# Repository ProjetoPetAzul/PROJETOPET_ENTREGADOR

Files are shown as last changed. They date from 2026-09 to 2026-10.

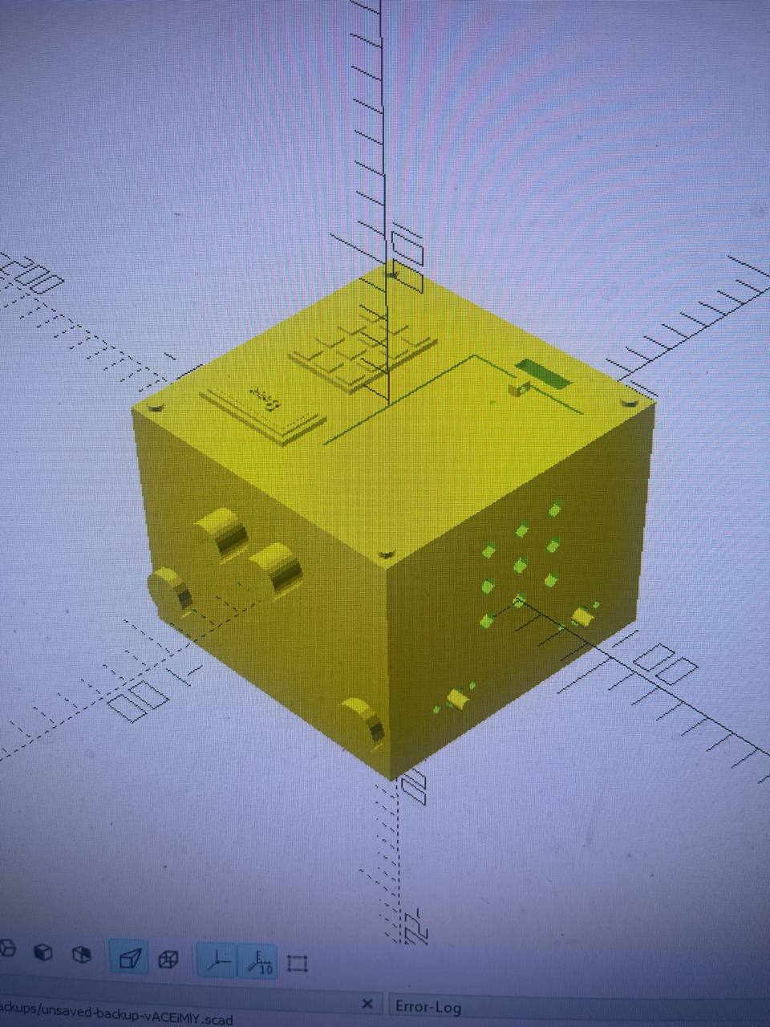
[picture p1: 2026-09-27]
media/images/openscad/photo_5010759403480747098_y.jpg

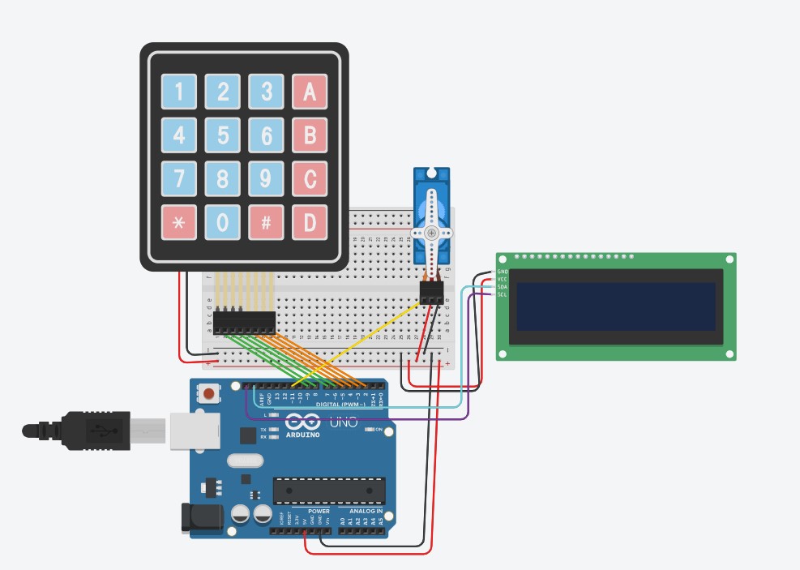
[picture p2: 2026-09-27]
media/images/tinkercad/Captura de tela 2026-09-27 202220.jpg

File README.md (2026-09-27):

# Robô Entregador

Projeto desenvolvido para a etapa **Core Project** do processo seletivo 2026.2 do **PET Engenharia de Computação — UFC**.

## Sobre o projeto

O **Robô Entregador** é uma proposta de robô autônomo desenvolvido para realizar o transporte de objetos entre diferentes pontos do **Centro de Tecnologia (CT) da Universidade Federal do Ceará (UFC)**.

A ideia consiste em selecionar um destino, realizar a coleta de um objeto e conduzi-lo autonomamente até o ponto escolhido, utilizando mecanismos de navegação, detecção de obstáculos e controle do compartimento de carga.

Durante o período de desenvolvimento do Core Project, a construção de um robô físico completamente funcional para navegação pelo CT não era viável. Por isso, a equipe desenvolveu um **protótipo integrado**, representando as principais partes necessárias para a construção do robô real:

* 🔌 **Eletrônica e controle**, desenvolvidos e simulados no Tinkercad com Arduino e C++;
* ⚙️ **Chassi e estrutura mecânica**, modelados em OpenSCAD;
* 🌐 **Simulação da navegação e do comportamento do robô**, desenvolvida no Webots.

O repositório reúne os códigos, modelos, documentação, simulações e materiais utilizados durante o desenvolvimento do projeto.

---

## Navegação pelo projeto

O repositório está organizado de acordo com as principais frentes de desenvolvimento do Robô Entregador.

| Seção | Conteúdo |
| --- | --- |
| 📚 [`docs/`](docs/) | Documentação técnica do projeto, incluindo eletrônica, mecânica, software, Webots e testes. |
| 📖 [`manual/`](manual/) | Manual do projeto, com orientações para utilização e compreensão do protótipo. |
| 🔌 [`arduino/`](arduino/) | Códigos dos Arduinos utilizados no sistema. |
| ⚙️ [`openscad/`](openscad/) | Modelo e arquivos relacionados ao chassi desenvolvido em OpenSCAD. |
| 🌐 [`webots/`](webots/) | Arquivos da simulação desenvolvida no Webots, incluindo mundo, textura e controlador. |
| 🖼️ [`media/`](media/) | Imagens, vídeos e materiais visuais do desenvolvimento e da apresentação. |
| 🔗 [`links/recursos.md`](links/recursos.md) | Links para recursos externos utilizados no projeto, incluindo o circuito desenvolvido no Tinkercad. |

---

## Visão geral do desenvolvimento

O projeto foi desenvolvido de forma modular, dividindo o protótipo em três frentes principais.

### Eletrônica e controle

Responsável pelo controle dos motores, sensores, teclado, display, iluminação, detecção de obstáculos e gerenciamento do compartimento de carga.

A implementação foi desenvolvida e testada no **Tinkercad**, utilizando dois Arduinos e comunicação entre eles por I²C.

➡️ [Ver documentação da eletrônica](docs/eletronica.md)

### Estrutura mecânica

O chassi e os elementos estruturais do robô foram modelados em **OpenSCAD**, considerando o posicionamento dos componentes eletrônicos e o compartimento destinado ao transporte da carga.

➡️ [Ver documentação mecânica](docs/mecanica.md)

### Simulação

O comportamento de navegação do robô foi representado no **Webots**, utilizando uma simulação baseada no ambiente do Centro de Tecnologia.

➡️ [Ver documentação do Webots](docs/webots.md)

---

## Desenvolvimento e testes

O projeto foi desenvolvido de forma incremental, com testes realizados ao longo das diferentes etapas de implementação.

A eletrônica passou por versões progressivas no Tinkercad, desde uma primeira abordagem simplificada até a integração de seleção de destino, teclado, senha, display e controle do compartimento de carga.

Também foram realizados testes das rotas e do comportamento de navegação na simulação do Webots. A integração física completa do robô não foi realizada durante o período do projeto, devido às limitações de tempo e recursos disponíveis.

➡️ [Ver histórico de desenvolvimento e testes](docs/testes.md)

---

## Recursos

### Circuito no Tinkercad

O circuito eletrônico desenvolvido durante o projeto pode ser acessado diretamente no Tinkercad:

➡️ [Abrir projeto no Tinkercad](links/recursos.md)

### Apresentação

Os slides utilizados na apresentação do projeto serão disponibilizados nesta seção futuramente.

➡️ [`media/slides/`](media/slides/)

---

## Estrutura do repositório

```text
robo-entregador/
├── README.md
├── arduino/
│   ├── mestre/
│   └── escravo/
├── docs/
├── manual/
├── media/
│   ├── images/
│   │   ├── tinkercad/
│   │   ├── openscad/
│   │   ├── webots/
│   │   └── prototipo/
│   ├── slides/
│   └── videos/
├── openscad/
├── webots/
└── links/
    └── recursos.md
```

Cada diretório possui uma função específica dentro do projeto, permitindo separar os códigos, modelos, documentação, simulações e materiais complementares.

---

## Equipe

Projeto desenvolvido por:

* **[HECTOR PIMENTA AVILA CAVALCANTE]**
* **[LIVIA SARAIVA DA COSTA]**
* **[MARCIO ROSA BEZERRA CAVALCANTE]**
* **[RENAN ARAUJO GONZALEZ]**

### Instituição

**Universidade Federal do Ceará — UFC**
**PET Engenharia de Computação**

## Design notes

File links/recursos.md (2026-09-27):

# Recursos externos

## Tinkercad

[🔗 Acessar o circuito do Robô Entregador no Tinkercad](https://www.tinkercad.com/things/074Hag8RQTY-robo-entregador-v4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)

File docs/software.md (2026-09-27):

# Software, Controle e Navegação

## 1. Visão geral

O software do **ROBÔ ENTREGADOR** é responsável por integrar as informações dos sensores, controlar os atuadores e coordenar todo o fluxo de operação do robô.

O firmware principal foi desenvolvido para Arduino utilizando **C++**, enquanto um segundo Arduino é utilizado especificamente para a leitura do teclado matricial.

A lógica do robô é organizada através de uma **máquina de estados**, permitindo separar as diferentes etapas da operação:

```text
Seleção do destino
        ↓
Preparação da carga
        ↓
Geração da senha
        ↓
Preparação da navegação
        ↓
Deslocamento
        ↓
Chegada ao destino
        ↓
Autenticação
        ↓
Entrega da carga
        ↓
Nova viagem
```

---

# 2. Organização do software

O firmware principal está localizado em:

```text
arduino/
└── mestre/
    └── mestre.ino
```

O firmware responsável pelo teclado está localizado em:

```text
arduino/
└── escravo/
    └── escravo.ino
```

O `mestre.ino` concentra a lógica principal do robô.

O `escravo.ino` realiza a leitura do teclado e disponibiliza as teclas através da comunicação I²C.

---

# 3. Máquina de estados

O comportamento do robô é controlado por estados que representam cada etapa da operação.

Os estados implementados são:

```text
ESCOLHENDO_DESTINO
AGUARDANDO_CARGA
MOSTRANDO_SENHA
DEVOLVENDO_CARGA
MANOBRA_INICIAL
SAINDO_DA_ORIGEM
EM_VIAGEM
AGUARDANDO_SENHA
PORTA_ABERTA
SISTEMA_BLOQUEADO
```

A utilização dessa estrutura evita que todas as operações sejam executadas simultaneamente e permite que cada etapa tenha suas próprias condições de entrada, execução e saída.

---

# 4. Estado `ESCOLHENDO_DESTINO`

É o estado inicial de operação do robô.

O sistema permanece parado e aguarda que o usuário informe a estação de destino através do teclado.

As estações disponíveis são:

```text
A
B
C
D
```

O destino não pode ser igual à estação atualmente ocupada pelo robô.

Após a seleção, o usuário utiliza:

```text
# → confirmar
* → cancelar
```

Quando o destino é confirmado, o sistema passa para:

```text
AGUARDANDO_CARGA
```

---

# 5. Estado `AGUARDANDO_CARGA`

Nesse estado, o compartimento de carga é aberto.

O sistema aguarda que o usuário coloque a carga no compartimento.

O usuário pode:

```text
# → confirmar que a carga foi colocada
* → cancelar
```

Caso a operação seja confirmada, o sistema fecha o compartimento e prepara a viagem.

Caso o usuário cancele, o compartimento é fechado e o sistema retorna à seleção de destino.

---

# 6. Geração da senha da viagem

Após a confirmação da carga, o firmware gera uma senha de quatro dígitos para a viagem.

A geração utiliza:

```cpp
random(0, 10)
```

O gerador é inicializado através de:

```cpp
randomSeed(micros());
```

A senha é apresentada no LCD antes do início do deslocamento.

O usuário precisa confirmar o início da viagem através da tecla:

```text
#
```

---

# 7. Estado `MOSTRANDO_SENHA`

Nesse estado, a senha da viagem permanece disponível para o usuário.

A senha funciona como uma credencial para retirar a carga na estação de destino.

O usuário pode iniciar a viagem pressionando:

```text
#
```

Também é possível cancelar a viagem através de:

```text
*
```

Nesse caso, o sistema passa para:

```text
DEVOLVENDO_CARGA
```

---

# 8. Estado `DEVOLVENDO_CARGA`

Esse estado trata o cancelamento de uma viagem depois que a carga já foi colocada no compartimento.

O fluxo é:

```text
Viagem cancelada
       ↓
Abrir compartimento
       ↓
Usuário retira a carga
       ↓
Fechar compartimento
       ↓
Retornar à seleção de destino
```

Dessa forma, uma viagem pode ser cancelada antes do deslocamento sem deixar a carga presa dentro do compartimento.

---

# 9. Representação da posição

O sistema representa a posição do robô através da estação atual.

As estações disponíveis são:

```text
A
B
C
D
```

Além da estação, o firmware mantém a orientação física do robô.

As orientações possíveis são:

```text
NORTE
LESTE
SUL
OESTE
```

Portanto, a navegação utiliza duas informações:

```text
Estação atual
+
Orientação atual
```

Exemplo:

```text
Estação atual = B
Orientação = OESTE
```

---

# 10. Rotas

As rotas entre as estações são determinadas pela função:

```cpp
obterDirecaoDestino()
```

O firmware possui as seguintes relações:

| Origem | Destino | Direção |
| --- | --- | --- |
| A | B | Leste |
| A | C | Norte |
| A | D | Oeste |
| B | A | Sul |
| B | C | Norte |
| B | D | Leste |
| C | A | Sul |
| C | B | Leste |
| C | D | Oeste |
| D | A | Leste |
| D | B | Oeste |
| D | C | Norte |

Essa tabela permite transformar a escolha do usuário em uma direção física necessária para o deslocamento.

---

# 11. Cálculo da manobra

Depois de determinar a direção desejada, o firmware compara essa direção com a orientação atual do robô.

A função utilizada é:

```cpp
calcularManobra()
```

As possibilidades são:

```text
RETO
DIREITA
ESQUERDA
U
```

Exemplo:

```text
Orientação atual: NORTE
Direção desejada: LESTE
```

Resultado:

```text
DIREITA
```

Outro exemplo:

```text
Orientação atual: NORTE
Direção desejada: OESTE
```

Resultado:

```text
ESQUERDA
```

Quando a direção desejada é oposta à orientação atual, é utilizada uma manobra de retorno em U.

---

# 12. Estado `MANOBRA_INICIAL`

Antes de iniciar o deslocamento, o robô precisa alinhar sua orientação com a direção da viagem.

Esse procedimento ocorre no estado:

```text
MANOBRA_INICIAL
```

Os tempos configurados no firmware são:

```text
Curva: 700 ms
Manobra U: 1400 ms
```

Se a orientação atual já estiver alinhada com a direção desejada, o robô segue sem realizar uma curva adicional.

---

# 13. Estado `SAINDO_DA_ORIGEM`

Após realizar a manobra inicial, o robô precisa deixar a região correspondente à estação de origem.

Isso é necessário porque a estação de origem continua sendo detectável enquanto o robô ainda estiver sobre sua marca.

O estado:

```text
SAINDO_DA_ORIGEM
```

mantém o robô seguindo a linha até que a estação de origem deixe de ser detectada.

O fluxo é:

```text
MANOBRA_INICIAL
       ↓
Seguir linha
       ↓
Ainda detecta origem?
    ↙          ↘
  SIM          NÃO
   ↓             ↓
Continua      EM_VIAGEM
```

---

# 14. Seguidor de linha

Durante o deslocamento, o robô utiliza três LDRs para determinar a posição da linha.

As leituras correspondem a:

```text
LDR esquerdo
LDR central
LDR direito
```

O firmware utiliza o limiar:

```text
300
```

Uma leitura inferior a esse valor é interpretada como detecção da linha.

---

# 15. Estratégia de recuperação da linha

O software mantém a variável:

```cpp
ultimaDirecao
```

Ela registra a última tendência conhecida do movimento:

```text
-1 → esquerda
 0 → frente
+1 → direita
```

Quando nenhum dos três sensores detecta a linha momentaneamente, o firmware utiliza essa informação para tentar recuperar a trajetória.

Isso permite que uma perda momentânea da linha não resulte imediatamente em uma interrupção completa do deslocamento.

---

# 16. Controle do movimento

O firmware possui comandos para controlar o movimento dos motores.

Os principais comportamentos são:

```text
Frente
Direita
Esquerda
Parada
```

Os movimentos de curva são realizados através do acionamento diferenciado dos motores.

Para uma curva à direita:

```text
Motor esquerdo → frente
Motor direito  → trás
```

Para uma curva à esquerda:

```text
Motor esquerdo → trás
Motor direito  → frente
```

Para uma parada:

```text
PWM esquerdo → 0
PWM direito  → 0
```

---

# 17. Estado `EM_VIAGEM`

Esse é o principal estado de deslocamento do robô.

Durante a viagem, o software realiza continuamente:

```text
Verificação de obstáculos
        ↓
Seguimento da linha
        ↓
Detecção de estação
```

A detecção de obstáculos possui prioridade sobre o seguimento da linha.

Quando uma estação é detectada depois que o robô deixou a origem, ela é considerada a estação de destino.

---

# 18. Detecção do destino

Durante a viagem, o sistema verifica continuamente os sensores responsáveis pela identificação das estações.

Quando uma estação é detectada:

```text
Motores → parada
```

O firmware atualiza:

```text
estacaoAtual
direcaoAtual
```

A orientação obtida é calculada através de:

```cpp
obterOrientacaoChegada()
```

Em seguida, o sistema passa para a etapa de autenticação.

---

# 19. Atualização da orientação

A orientação física do robô é atualizada após cada viagem.

Isso permite que a próxima viagem considere a posição final deixada pela viagem anterior.

Assim, o planejamento de uma nova rota utiliza:

```text
estação atual
+
orientação atual
+
estação de destino
```

Essa abordagem permite calcular a próxima manobra sem precisar assumir que o robô sempre começa voltado para a mesma direção.

---

# 20. Detecção de obstáculos

A navegação possui dois sensores ultrassônicos.

O software verifica a distância medida pelos sensores e considera que existe um obstáculo quando qualquer um deles apresenta distância inferior a:

```text
30 cm
```

Quando um obstáculo é detectado:

```text
Parar motores
```

O robô permanece parado enquanto a condição de obstáculo persistir.

---

# 21. Atualização das leituras ultrassônicas

As leituras dos sensores ultrassônicos são atualizadas aproximadamente a cada:

```text
100 ms
```

A leitura utiliza:

```cpp
pulseIn(echo, HIGH, 30000)
```

O timeout utilizado é de aproximadamente:

```text
30 ms
```

Quando não há retorno do sinal dentro desse período, o firmware considera que não existe obstáculo detectado dentro da condição utilizada.

---

# 22. Prioridade dos obstáculos

Durante a viagem, a lógica pode ser representada por:

```text
              EM_VIAGEM
                  ↓
        Verificar obstáculo
                  ↓
          Existe obstáculo?
             ↙         ↘
           SIM         NÃO
            ↓            ↓
      Parar motores   Seguir linha
            ↓            ↓
       Aguardar       Verificar
                      estação
```

Caso o obstáculo permaneça por aproximadamente dois segundos, o LCD apresenta:

```text
OBSTACULO NA VIA
```

Quando a condição deixa de existir, o sistema retoma o fluxo normal da viagem.

---

# 23. Estado `AGUARDANDO_SENHA`

Após identificar a estação de destino, o robô permanece parado e solicita a senha da viagem.

O usuário deve informar os quatro dígitos através do teclado.

Por questões de segurança visual, os valores digitados são apresentados no LCD como:

```text
*
```

A tecla:

```text
*
```

pode ser utilizada para limpar a entrada atual.

A tecla:

```text
#
```

confirma a senha.

---

# 24. Validação da senha

O firmware compara a senha digitada com a senha gerada no início da viagem.

Caso os valores sejam iguais:

```text
Senha correta
       ↓
Acesso liberado
       ↓
Abrir compartimento
       ↓
Retirar carga
```

O sistema então passa para:

```text
PORTA_ABERTA
```

---

# 25. Tentativas de autenticação

O sistema permite até:

```text
3 tentativas
```

de autenticação para cada viagem.

Quando a senha está incorreta, o número de tentativas restantes é atualizado.

Depois de três tentativas incorretas, o sistema entra em:

```text
SISTEMA_BLOQUEADO
```

O código de manutenção utilizado para desbloqueio é definido diretamente no firmware e não é apresentado nesta documentação.

---

# 26. Estado `SISTEMA_BLOQUEADO`

Nesse estado, o sistema deixa de aceitar a senha normal da viagem.

O usuário precisa realizar o procedimento de manutenção definido pelo firmware.

Após a autenticação de manutenção, o sistema pode retornar ao fluxo de autenticação.

Essa estrutura impede que a mesma senha da viagem continue sendo testada indefinidamente.

---

# 27. Estado `PORTA_ABERTA`

Quando a senha correta é informada, o compartimento é aberto.

O LCD informa que a carga pode ser retirada.

Após a retirada, o usuário pode utilizar:

```text
#
```

ou:

```text
*
```

para finalizar a operação.

O servo então fecha o compartimento e o sistema retorna para:

```text
ESCOLHENDO_DESTINO
```

---

# 28. Comunicação com o teclado

O Arduino principal não realiza diretamente a varredura da matriz do teclado.

Essa função é executada pelo segundo Arduino.

A comunicação entre os dois dispositivos ocorre através de I²C.

O Arduino do teclado possui o endereço:

```text
0x10
```

O Arduino principal realiza uma requisição e o Arduino 2 retorna o caractere armazenado.

---

# 29. Estados sem leitura do teclado

Durante o deslocamento, não é necessário consultar o teclado.

Por isso, as requisições de teclado não são realizadas durante:

```text
MANOBRA_INICIAL
SAINDO_DA_ORIGEM
EM_VIAGEM
```

O teclado é consultado principalmente nos estados em que existe uma interação direta com o usuário.

Essa organização evita que a leitura do teclado interfira desnecessariamente na execução da navegação.

---

# 30. Controle do compartimento

O compartimento é controlado através de um micro servo.

As posições utilizadas são:

```text
0°  → fechado
90° → aberto
```

O software realiza a abertura e o fechamento conforme o estado atual do sistema.

A abertura ocorre principalmente durante:

```text
AGUARDANDO_CARGA
PORTA_ABERTA
```

Também pode ocorrer durante o processo de cancelamento para permitir a retirada da carga.

---

# 31. Fluxo completo de operação

O funcionamento completo pode ser representado por:

```text
INÍCIO
  ↓
ESCOLHENDO_DESTINO
  ↓
Selecionar destino
  ↓
Confirmar
  ↓
AGUARDANDO_CARGA
  ↓
Colocar carga
  ↓
Confirmar
  ↓
MOSTRANDO_SENHA
  ↓
Gerar senha
  ↓
Confirmar início
  ↓
MANOBRA_INICIAL
  ↓
SAINDO_DA_ORIGEM
  ↓
EM_VIAGEM
  ↓
Seguir linha
  ↓
Verificar obstáculos
  ↓
Detectar destino
  ↓
AGUARDANDO_SENHA
  ↓
Informar senha
  ↓
Senha correta?
 ↙          ↘
SIM         NÃO
 ↓           ↓
PORTA_       Tentativa
ABERTA       novamente
 ↓
Retirar carga
 ↓
Fechar compartimento
 ↓
ESCOLHENDO_DESTINO
```

---

# 32. Fluxo de cancelamento

O cancelamento antes do deslocamento segue:

```text
AGUARDANDO_CARGA
        ↓
Carga colocada
        ↓
MOSTRANDO_SENHA
        ↓
Usuário pressiona *
        ↓
DEVOLVENDO_CARGA
        ↓
Abrir compartimento
        ↓
Retirar carga
        ↓
Fechar compartimento
        ↓
ESCOLHENDO_DESTINO
```

---

# 33. Fluxo de bloqueio

Quando a autenticação falha três vezes:

```text
AGUARDANDO_SENHA
        ↓
Tentativa 1
        ↓
Tentativa 2
        ↓
Tentativa 3
        ↓
SISTEMA_BLOQUEADO
        ↓
Procedimento de manutenção
        ↓
Retorno à autenticação
```

---

# 34. Inicialização do software

Durante o `setup()`, o firmware realiza as configurações iniciais do sistema.

Entre elas:

1. configuração dos pinos;
2. inicialização da comunicação I²C;
3. configuração do LCD;
4. configuração dos sensores;
5. configuração do controle dos motores;
6. desligamento dos LEDs;
7. parada dos motores;
8. fechamento do compartimento;
9. inicialização do gerador aleatório;
10. definição da estação inicial;
11. definição da orientação inicial;
12. apresentação da tela inicial.

A condição inicial é:

```text
Estação = A
Orientação = NORTE
```

---

# 35. Parâmetros de controle

Os principais parâmetros utilizados pelo software são:

| Parâmetro | Valor |
| --- | ---: |
| Velocidade dos motores | 128 |
| Limiar dos LDRs de linha | 300 |
| Limiar dos sensores de estação | 100 |
| Distância para obstáculo | 30 cm |
| Atualização ultrassônica |  100 ms |
| Timeout ultrassônico | 30 ms |
| Tempo de curva |  700 ms |
| Tempo da manobra U | 1400 ms |
| Tempo do servo |  500 ms |
| Tentativas de senha | 3 |

Esses valores estão definidos diretamente no firmware e podem ser ajustados durante o desenvolvimento e os testes do protótipo.

---

# 36. Estrutura lógica do firmware

A organização geral do programa pode ser representada como:

```text
Configuração
     ↓
Definição de estados
     ↓
Definição de direções
     ↓
Definição de manobras
     ↓
Controle de motores
     ↓
Leitura dos sensores
     ↓
Seguidor de linha
     ↓
Detecção de estações
     ↓
Detecção de obstáculos
     ↓
Controle do servo
     ↓
Comunicação I²C
     ↓
Interface com usuário
     ↓
Senhas
     ↓
Máquina de estados
```

Essa estrutura permite que cada subsistema tenha uma responsabilidade definida dentro do funcionamento do robô.

---

# 37. Integração entre software e hardware

O software funciona como a camada responsável por interpretar os sensores e controlar os atuadores.

A relação pode ser representada por:

```text
                 SENSORES
                    ↓
          ┌──────────────────┐
          │ Arduino Principal│
          │                  │
          │ Máquina de       │
          │ estados          │
          │                  │
          │ Navegação        │
          └────────┬─────────┘
                   ↓
        ┌──────────┼──────────┐
        ↓          ↓          ↓
     MOTORES     SERVO      LEDs
        ↓          ↓          ↓
    Movimento  Compart.   Indicação

                   ↕
                  I²C
                   ↕
          ┌────────────────┐
          │   Arduino 2    │
          └───────┬────────┘
                  ↓
             TECLADO 4×4
```

O Arduino principal funciona como o núcleo de decisão do sistema, enquanto o segundo Arduino atua como uma interface dedicada para entrada de dados.

---

# 38. Arquivos relacionados

Os principais arquivos relacionados ao software são:

```text
arduino/
├── mestre/
│   └── mestre.ino
└── escravo/
    └── escravo.ino
```

O arquivo `mestre.ino` contém:

* máquina de estados;
* navegação;
* controle dos motores;
* leitura dos sensores;
* controle do servo;
* controle do LCD;
* comunicação I²C;
* gerenciamento das senhas.

O arquivo `escravo.ino` contém:

* varredura do teclado;
* identificação das teclas;
* armazenamento temporário da tecla;
* resposta às requisições I²C.

---

# 39. Relação com as outras etapas do projeto

O software integra as demais partes desenvolvidas no projeto:

```text
Eletrônica
    ↓
Sensores e atuadores
    ↓
Software
    ↓
Controle e navegação
    ↓
Mecânica
    ↓
Estrutura física
    ↓
Webots
    ↓
Simulação do comportamento
```

Dessa forma, o firmware representa a camada de controle que conecta os componentes eletrônicos à lógica de operação do robô.

---

## 40. Arquivos do projeto

| Área | Arquivo |
| --- | --- |
| Firmware principal  | `arduino/mestre/mestre.ino` |
| Firmware do teclado | `arduino/escravo/escravo.ino` |
| Modelo mecânico | `openscad/chassi.scad` |
| Simulação | `webots/` |

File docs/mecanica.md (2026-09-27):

# Mecânica e Modelagem 3D

## 1. Visão geral

A estrutura mecânica do **ROBÔ ENTREGADOR** foi desenvolvida utilizando **OpenSCAD**, permitindo criar um modelo paramétrico do chassi e dos principais elementos externos do protótipo.

O projeto foi pensado para representar a estrutura física de um robô móvel capaz de transportar uma carga, integrando:

* chassi;
* tampa superior;
* compartimento de carga;
* alçapão;
* pontos de fixação;
* suportes internos;
* aberturas para sensores;
* representação dos componentes eletrônicos externos.

A modelagem foi construída de forma paramétrica, permitindo alterar dimensões e características da estrutura diretamente através das variáveis do código.

---

## 2. Arquivo do modelo

O modelo mecânico está localizado em:

```text
openscad/
└── chassi.scad
```

O arquivo contém a definição das principais peças e também uma montagem final do conjunto.

---

## 3. Dimensões principais

As dimensões principais utilizadas no modelo são:

| Parâmetro |  Valor |
| --- | -----: |
| Largura do chassi |  48 mm |
| Comprimento do chassi | 104 mm |
| Altura do chassi |  65 mm |
| Espessura das paredes | 3 mm |
| Distância da quina | 4 mm |
| Raio dos furos de parafuso | 1,6 mm |

Esses valores são definidos no início do arquivo OpenSCAD, permitindo que o modelo seja facilmente ajustado.

---

## 4. Estrutura do chassi

O corpo principal do chassi é construído a partir de um volume retangular com:

```text
48 mm × 104 mm × 65 mm
```

A estrutura externa é posteriormente modificada para criar o espaço interno do robô.

A espessura das paredes é definida por:

```text
3 mm
```

Isso permite representar uma carcaça com volume interno suficiente para acomodar os componentes do sistema.

---

## 5. Base modular

A parte inferior do chassi possui uma matriz de furos inspirada no padrão de montagem utilizado em peças LEGO.

A configuração principal utiliza uma matriz de:

```text
6 × 13
```

Essa característica permite representar pontos de fixação distribuídos pela base.

Além da matriz principal, existem furos adicionais nas extensões laterais da estrutura.

---

## 6. Extensões laterais

O modelo possui uma extensão lateral localizada na região inferior do chassi.

Essa extensão possui aproximadamente:

```text
64 mm de largura
24 mm de comprimento
5 mm de altura
```

Também são adicionados furos de montagem nessa região.

Essas extensões fazem parte da geometria da base e ampliam as possibilidades de fixação da estrutura.

---

## 7. Compartimento de carga

Um dos principais elementos mecânicos do projeto é o compartimento destinado ao transporte da carga.

A estrutura possui uma região elevada na tampa para representar o compartimento.

As dimensões principais utilizadas nessa região são aproximadamente:

```text
26 mm × 35 mm × 15 mm
```

O compartimento é integrado ao modelo da tampa e possui pontos próprios de fixação.

---

## 8. Alçapão

O acesso ao compartimento de carga é representado através de um **alçapão**.

A peça possui espessura aproximada de:

```text
1,2 mm
```

O modelo também inclui elementos geométricos para representar:

* a porta do compartimento;
* a região de abertura;
* uma alça;
* o mecanismo semelhante a uma dobradiça.

No protótipo eletrônico, a abertura do compartimento é realizada por um micro servo. O modelo mecânico representa a estrutura física correspondente a esse mecanismo.

---

## 9. Fixação da tampa

A tampa superior possui quatro pontos de fixação localizados nas regiões de canto.

Esses pontos são representados através de furos para parafusos.

O modelo também possui quatro torres internas de montagem, destinadas à representação dos pontos de suporte internos da estrutura.

---

## 10. Aberturas para sensores ultrassônicos

A parte frontal do chassi possui duas aberturas destinadas aos sensores ultrassônicos.

Os furos são modelados com raio aproximado de:

```text
8,2 mm
```

A disposição dos dois furos representa a posição dos sensores utilizados para detectar obstáculos à frente do robô.

---

## 11. Abertura para chave

Na região traseira do chassi existe um recorte destinado à representação de uma **chave gangorra**.

O modelo da chave também foi criado no próprio OpenSCAD para permitir sua visualização durante a montagem.

---

## 12. Ventilação

O chassi possui aberturas laterais destinadas à representação de entradas e saídas de ventilação.

Essas aberturas fazem parte da geometria lateral da carcaça.

---

## 13. Componentes representados no modelo

Além da estrutura principal, o arquivo OpenSCAD possui modelos simplificados de alguns componentes utilizados no protótipo.

Entre eles estão:

* sensores ultrassônicos;
* chave gangorra;
* LCD;
* teclado matricial;
* parafusos.

Esses modelos não têm como objetivo reproduzir todos os detalhes construtivos dos componentes comerciais, mas representar suas dimensões e posições dentro da montagem.

---

## 14. Modelo do sensor ultrassônico

O sensor ultrassônico é representado por um modelo aproximado de:

```text
45 mm × 2 mm × 20 mm
```

A parte frontal possui dois elementos cilíndricos com aproximadamente:

```text
8 mm de raio
```

A representação permite visualizar a posição dos sensores em relação à abertura frontal do chassi.

---

## 15. Modelo do LCD

O display LCD é representado por um modelo simplificado com dimensões aproximadas de:

```text
40 mm × 20 mm × 2 mm
```

Também é incluída uma representação textual na superfície do display para facilitar sua identificação na montagem.

---

## 16. Modelo do teclado

O teclado matricial é representado por uma placa com dimensões aproximadas de:

```text
30 mm × 40 mm × 2 mm
```

A superfície possui uma representação das teclas em uma matriz de:

```text
3 × 4
```

O objetivo dessa modelagem é representar a posição e o volume ocupado pelo dispositivo na estrutura do protótipo.

---

## 17. Modelo da chave gangorra

A chave gangorra possui um modelo simplificado próprio dentro do arquivo OpenSCAD.

Sua função na montagem é representar visualmente o componente instalado na parte traseira do chassi.

---

## 18. Modelo dos parafusos

Os parafusos utilizados nos pontos de fixação são representados através de uma geometria simplificada.

A dimensão relacionada ao raio do parafuso é definida pelo parâmetro:

```text
raio_parafuso = 1,6 mm
```

Essa parametrização permite ajustar os furos de fixação de acordo com a necessidade do modelo.

---

## 19. Organização do código OpenSCAD

O arquivo foi organizado em módulos, permitindo construir cada parte da estrutura separadamente.

Entre as principais funções geométricas estão:

```text
chassi()
tampa()
alcapao()
parafuso()
sensor_ultrassonico()
chave_gangorra()
tela_lcd()
teclado()
```

Essa organização facilita a edição individual dos componentes e a montagem final do protótipo.

---

## 20. Montagem final

Após a definição das peças individuais, o arquivo realiza a montagem do conjunto.

A montagem integra:

```text
Chassi
   ↓
Tampa
   ↓
Alçapão
   ↓
Parafusos
   ↓
Sensores ultrassônicos
   ↓
Chave gangorra
   ↓
LCD
   ↓
Teclado
```

Dessa forma, é possível visualizar a relação espacial entre a estrutura mecânica e os principais componentes externos do robô.

---

## 21. Relação entre mecânica e eletrônica

A modelagem mecânica foi desenvolvida considerando os componentes utilizados na implementação eletrônica.

A estrutura possui regiões específicas para:

* sensores ultrassônicos;
* LCD;
* teclado;
* chave;
* compartimento de carga;
* pontos de fixação;
* componentes internos.

Assim, o modelo não representa somente uma carcaça, mas uma proposta de integração entre a estrutura física e os subsistemas eletrônicos do robô.

---

## 22. Relação com o projeto do robô

O modelo mecânico representa uma etapa do desenvolvimento do protótipo do **ROBÔ ENTREGADOR**.

A proposta geral do projeto é integrar:

```text
Mecânica
   +
Eletrônica
   +
Software
   +
Simulação
```

A modelagem em OpenSCAD permite representar como esses sistemas poderiam ser fisicamente integrados em uma versão construída do robô.

---

## 23. Arquivo relacionado

O modelo completo está disponível no repositório em:

```text
openscad/chassi.scad
```

O arquivo pode ser aberto e editado no **OpenSCAD**, permitindo visualizar a geometria, modificar os parâmetros e gerar novamente o modelo tridimensional.

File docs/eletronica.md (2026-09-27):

# Eletrônica e Firmware

## 1. Visão geral

O **ROBÔ ENTREGADOR** é um protótipo de robô móvel autônomo desenvolvido para transportar uma carga entre quatro estações identificadas pelas letras **A, B, C e D**.

A implementação eletrônica combina:

* Arduino;
* dois motores DC;
* driver L293D;
* três sensores LDR para seguimento de linha;
* sensores para identificação das estações;
* dois sensores ultrassônicos;
* micro servo para acionamento do compartimento de carga;
* display LCD 16×2 com comunicação I²C;
* expansor de I/O PCF8574;
* teclado matricial 4×4;
* comunicação I²C entre dois Arduinos.

O sistema de controle é organizado por uma **máquina de estados**, permitindo separar as etapas de interação com o usuário, preparação da carga, navegação e entrega.

---

## 2. Arquitetura eletrônica

O sistema utiliza dois Arduinos.

### Arduino principal

O Arduino principal concentra a lógica de controle e é responsável por:

* controle dos motores;
* leitura dos sensores de linha;
* detecção das estações;
* leitura dos sensores ultrassônicos;
* controle do servo;
* controle do LCD;
* controle dos LEDs através do PCF8574;
* comunicação com o Arduino do teclado;
* geração das senhas;
* validação das senhas;
* controle das tentativas;
* lógica de navegação;
* máquina de estados.

### Arduino 2

O segundo Arduino é dedicado ao teclado matricial 4×4.

Ele:

1. realiza a varredura das linhas e colunas;
2. identifica a tecla pressionada;
3. armazena temporariamente o caractere;
4. disponibiliza a tecla através do barramento I²C.

O Arduino 2 funciona como **escravo I²C no endereço `0x10`**.

Essa divisão permite separar a leitura do teclado da lógica principal do robô.

---

# 3. Componentes principais

| Componente | Função |
| --- | --- |
| Arduino principal | Controle central do robô |
| Arduino 2 | Leitura do teclado |
| L293D | Acionamento dos motores DC |
| 2 motores DC | Deslocamento do robô |
| 3 LDRs | Seguimento da linha |
| Sensores de estação | Identificação das estações |
| 2 HC-SR04 | Detecção de obstáculos |
| Micro servo | Abertura e fechamento do compartimento |
| LCD 16×2 I²C | Interface de usuário |
| PCF8574 | Expansão de saídas para LEDs |
| Teclado 4×4 | Entrada de comandos e senhas |

---

# 4. Pinagem do Arduino principal

## 4.1 Motores

| Pino | Função |
| ---- | --- |
| D5 | PWM do motor esquerdo |
| D6 | PWM do motor direito  |
| D7 | IN1 do motor esquerdo |
| D8 | IN2 do motor esquerdo |
| D9 | IN1 do motor direito  |
| D10  | IN2 do motor direito  |

O controle dos motores é realizado através do **L293D**.

A velocidade padrão configurada no firmware é:

```text
128 / 255
```

---

## 4.2 Sensores do seguidor de linha

| Pino | Sensor |
| ---- | --- |
| A0 | LDR esquerdo |
| A1 | LDR central  |
| A2 | LDR direito  |

O firmware utiliza:

```text
LIMIAR_LDR = 300
```

A condição utilizada é:

```text
valor < 300 → linha detectada
```

---

## 4.3 Sensores de estação

| Pino | Função |
| ---- | --- |
| A3 | LDR esquerdo da estação |
| D4 | Sensor digital direito da estação |

Uma estação somente é considerada detectada quando as duas condições são satisfeitas:

```text
LDR esquerdo < 100
E
sensor digital = LOW
```

A utilização simultânea dos dois sensores reduz a possibilidade de uma leitura isolada ser interpretada como uma estação.

---

## 4.4 Sensores ultrassônicos

### Sensor esquerdo

| Função | Pino |
| --- | ---- |
| TRIG | D11  |
| ECHO | D12  |

### Sensor direito

| Função | Pino |
| --- | ---- |
| TRIG | D3 |
| ECHO | D13  |

O limite configurado para detecção de obstáculos é:

```text
30 cm
```

---

## 4.5 Servo

| Pino | Função |
| ---- | --- |
| D2 | Servo do compartimento |

Posições utilizadas pelo firmware:

```text
0°  → fechado
90° → aberto
```

O tempo configurado para movimentação é de:

```text
500 ms
```

---

# 5. Seguidor de linha

O robô utiliza três LDRs para acompanhar a pista.

As leituras são convertidas em estados booleanos de acordo com o limiar configurado.

### Principais combinações

| Esquerdo | Centro | Direito | Ação |
| --- | --- | --- | --- |
| 1 | 0 | 0 | Virar à esquerda |
| 1 | 1 | 0 | Virar à esquerda |
| 0 | 1 | 0 | Seguir em frente |
| 0 | 1 | 1 | Virar à direita |
| 0 | 0 | 1 | Virar à direita |
| 0 | 0 | 0 | Utilizar última direção |
| Outros | | | Seguir em frente |

O firmware mantém a variável:

```cpp
ultimaDirecao
```

Ela registra a última tendência de movimento:

```text
-1 → esquerda
 0 → frente
+1 → direita
```

Quando nenhum sensor detecta a linha momentaneamente, o robô utiliza essa informação para tentar recuperar a trajetória.

---

# 6. Controle dos motores

O firmware possui quatro movimentos básicos.

### Frente

Os dois motores giram para frente.

### Direita

O motor esquerdo gira para frente e o direito para trás.

### Esquerda

O motor esquerdo gira para trás e o direito para frente.

### Parada

Os dois sinais PWM são zerados.

Essa configuração também permite realizar giros aproximadamente sobre o próprio eixo.

---

# 7. Detecção de obstáculos

A detecção de obstáculos é realizada por dois sensores ultrassônicos.

O firmware mede a distância dos dois sensores e considera que existe obstáculo quando qualquer um deles retorna uma distância inferior a:

```text
30 cm
```

Quando um obstáculo é identificado:

```text
motores → parada
```

O robô permanece parado enquanto a condição de obstáculo persistir.

---

## 7.1 Timeout dos sensores

A leitura dos HC-SR04 utiliza:

```cpp
pulseIn(echo, HIGH, 30000)
```

Portanto, o tempo máximo de espera pelo eco é de aproximadamente:

```text
30 ms
```

Quando não há retorno dentro desse período, o firmware considera que não existe obstáculo dentro do alcance utilizado.

---

## 7.2 Cache das leituras

As leituras dos sensores ultrassônicos são atualizadas em intervalos de aproximadamente:

```text
100 ms
```

Isso evita executar continuamente os dois `pulseIn()` em todas as iterações do `loop()`.

Dessa forma, o sistema mantém uma resposta adequada aos obstáculos sem bloquear excessivamente o restante da lógica.

---

# 8. Detecção das estações

As estações são identificadas através da combinação de dois sensores.

O firmware utiliza:

```cpp
LDR_EST_ESQ = A3
LDR_EST_DIR = 4
```

A estação é considerada detectada somente quando:

```text
LDR da estação < 100
```

e:

```text
sensor digital = LOW
```

Essa condição é importante durante a navegação porque o robô utiliza a detecção da estação para determinar quando chegou ao destino.

---

# 9. Sistema de navegação

O sistema possui quatro estações:

```text
A
B
C
D
```

Além da estação atual, o firmware mantém a orientação física do robô.

As orientações possíveis são:

```text
NORTE
LESTE
SUL
OESTE
```

Assim, o estado de navegação não é representado somente por:

```text
estação atual = B
```

mas também por:

```text
estação atual = B
orientação atual = OESTE
```

Essa informação permite calcular a manobra necessária para a próxima viagem.

---

# 10. Direção do destino

A função:

```cpp
obterDirecaoDestino()
```

determina a direção física necessária para cada combinação de origem e destino.

As rotas implementadas são:

| Origem | Destino | Direção |
| --- | --- | --- |
| A | B | Leste |
| A | C | Norte |
| A | D | Oeste |
| B | A | Sul |
| B | C | Norte |
| B | D | Leste |
| C | A | Sul |
| C | B | Leste |
| C | D | Oeste |
| D | A | Leste |
| D | B | Oeste |
| D | C | Norte |

---

# 11. Orientação após a chegada

A função:

```cpp
obterOrientacaoChegada()
```

atualiza a orientação física do robô após cada deslocamento.

Isso permite que uma viagem seguinte utilize a orientação obtida na viagem anterior.

A posição e a orientação são, portanto, informações independentes.

---

# 12. Cálculo da manobra

A função:

```cpp
calcularManobra()
```

compara:

```text
direcaoAtual
```

com:

```text
direcaoDesejada
```

e seleciona uma das seguintes manobras:

```text
RETO
DIREITA
ESQUERDA
U
```

### Exemplo

Se:

```text
direção atual = NORTE
direção desejada = LESTE
```

a manobra é:

```text
DIREITA
```

Se:

```text
direção atual = NORTE
direção desejada = OESTE
```

a manobra é:

```text
ESQUERDA
```

Quando as direções são opostas, o firmware utiliza:

```text
U
```

---

# 13. Manobra inicial

Antes de iniciar o seguimento da linha, o robô executa a manobra necessária para alinhar sua orientação com a direção do deslocamento.

Os tempos configurados são:

```text
Curva: 700 ms
Retorno U: 1400 ms
```

Essa etapa é controlada pelo estado:

```text
MANOBRA_INICIAL
```

Se o robô estiver na direção correta, nenhuma curva adicional é realizada.

---

# 14. Saída da estação de origem

O estado:

```text
SAINDO_DA_ORIGEM
```

evita que a própria estação de origem seja imediatamente interpretada como destino.

O fluxo é:

```text
Manobra inicial
      ↓
Começa a seguir a linha
      ↓
Ainda está sobre a origem?
      ↓
Sim → continua
      ↓
Não
      ↓
EM_VIAGEM
```

Somente depois que a condição da estação de origem deixa de ser detectada o sistema passa a procurar a estação de destino.

---

# 15. Viagem

Durante o estado:

```text
EM_VIAGEM
```

o firmware executa continuamente:

1. verificação de obstáculos;
2. parada caso exista obstáculo;
3. seguimento da linha;
4. detecção de estação.

Quando uma estação é detectada depois que o robô deixou a origem:

```text
motores → parada
```

O firmware então atualiza:

```text
estacaoAtual
direcaoAtual
```

e inicia o processo de autenticação no destino.

---

# 16. Comunicação I²C

O Arduino principal utiliza o barramento I²C através dos pinos:

```text
A4 → SDA
A5 → SCL
```

Os dispositivos conectados ao barramento são:

| Dispositivo | Endereço |
| --- | --- |
| LCD 16×2 | `0x27` |
| PCF8574 | `0x20` |
| Arduino 2 | `0x10` |

A velocidade configurada no firmware é:

```text
400 kHz
```

---

# 17. LCD

O display utilizado é um:

```text
LCD 16×2 I²C
```

com endereço:

```text
0x27
```

Ele apresenta as informações necessárias para a operação do robô.

Exemplos de telas:

```text
ORIGEM: A
DESTINO? (A-D)
```

```text
DESTINO: B
#=OK *=VOLTA
```

```text
COLOQUE A CARGA
#=OK *=CANCELA
```

```text
A -> B
EM VIAGEM
```

```text
DIGITE A SENHA
____
```

---

# 18. PCF8574 e LEDs

O PCF8574 é utilizado como expansor de entradas e saídas.

Endereço:

```text
0x20
```

Os LEDs utilizam lógica ativa em nível baixo:

```text
LOW  → ligado
HIGH → desligado
```

Mapeamento utilizado:

| Pino | Função |
| ---- | --- |
| P4 | LED da estação B |
| P5 | LED da estação C |
| P6 | LED da estação D |
| P7 | LED associado à estação A |

Durante uma viagem, o LED correspondente ao destino é ativado.

Após a chegada, os LEDs são desligados.

---

# 19. Arduino 2 — teclado

O Arduino 2 funciona como escravo I²C:

```text
endereço = 0x10
```

O teclado utilizado é uma matriz 4×4.

### Linhas

| Linha | Pino |
| ----- | ---- |
| R1 | D2 |
| R2 | D3 |
| R3 | D4 |
| R4 | D5 |

### Colunas

| Coluna | Pino |
| --- | ---- |
| C1 | D6 |
| C2 | D7 |
| C3 | D8 |
| C4 | D9 |

O mapeamento das teclas é:

```text
1  2  3  A
4  5  6  B
7  8  9  C
*  0  #  D
```

O Arduino 2 realiza a varredura da matriz e armazena a tecla pressionada.

Quando recebe uma requisição I²C do Arduino principal, envia o caractere armazenado.

---

# 20. Controle do teclado

O Arduino principal consulta o teclado somente nos estados em que uma entrada do usuário é necessária.

Durante:

```text
MANOBRA_INICIAL
SAINDO_DA_ORIGEM
EM_VIAGEM
```

não são realizadas requisições de teclado.

O intervalo mínimo entre leituras é:

```text
50 ms
```

No Arduino 2 também existe uma pequena espera para evitar múltiplas leituras da mesma tecla.

---

# 21. Compartimento de carga

O compartimento é acionado por um micro servo.

Posições:

```text
0°  → fechado
90° → aberto
```

O servo é acionado somente quando necessário.

### Abertura

Pode ocorrer:

* antes da colocação da carga;
* quando a viagem é cancelada após a carga ter sido colocada;
* quando a senha do destino é validada.

### Fechamento

Pode ocorrer:

* após a colocação da carga;
* durante o cancelamento;
* após a retirada da carga;
* durante a inicialização do sistema.

---

# 22. Sistema de senha

Cada viagem possui uma senha de quatro dígitos.

A senha é gerada através do gerador pseudoaleatório do Arduino:

```cpp
random(0, 10)
```

O gerador é inicializado utilizando:

```cpp
randomSeed(micros());
```

A senha é apresentada ao usuário antes do início da viagem.

O usuário precisa pressionar `#` para iniciar o deslocamento.

---

# 23. Cancelamento antes da viagem

Depois que a carga é colocada e a senha é apresentada, o usuário pode cancelar a viagem através da tecla:

```text
*
```

Nesse caso:

1. o compartimento é reaberto;
2. o usuário retira a carga;
3. o compartimento é fechado;
4. o sistema retorna à seleção de destino.

Essa etapa é representada pelo estado:

```text
DEVOLVENDO_CARGA
```

---

# 24. Autenticação no destino

Quando o robô chega ao destino, solicita a senha da viagem.

Os dígitos digitados são apresentados como:

```text
*
```

em vez dos valores reais.

A tecla:

```text
*
```

limpa a senha atual.

A tecla:

```text
#
```

confirma a entrada.

---

# 25. Senha correta

Quando a senha está correta:

```text
ACESSO LIBERADO
RETIRE A CARGA
```

O servo abre o compartimento.

O usuário retira a carga.

Depois, `#` ou `*` fecha o compartimento e o sistema retorna à seleção de uma nova viagem.

---

# 26. Tentativas de autenticação

O firmware permite até:

```text
3 tentativas
```

de senha para a viagem.

Após três tentativas incorretas, o sistema entra no estado:

```text
SISTEMA_BLOQUEADO
```

Nesse estado, a senha normal da viagem deixa de ser processada e o sistema solicita o código de manutenção definido no firmware.

O código de manutenção é armazenado diretamente no programa e deve ser tratado como uma informação de configuração do protótipo.

---

# 27. Máquina de estados

O funcionamento do sistema é organizado através dos seguintes estados:

```text
ESCOLHENDO_DESTINO
AGUARDANDO_CARGA
MOSTRANDO_SENHA
DEVOLVENDO_CARGA
MANOBRA_INICIAL
SAINDO_DA_ORIGEM
EM_VIAGEM
AGUARDANDO_SENHA
PORTA_ABERTA
SISTEMA_BLOQUEADO
```

Fluxo principal:

```text
ESCOLHENDO_DESTINO
        ↓
AGUARDANDO_CARGA
        ↓
MOSTRANDO_SENHA
        ↓
MANOBRA_INICIAL
        ↓
SAINDO_DA_ORIGEM
        ↓
EM_VIAGEM
        ↓
AGUARDANDO_SENHA
        ↓
PORTA_ABERTA
        ↓
ESCOLHENDO_DESTINO
```

Fluxo de cancelamento:

```text
MOSTRANDO_SENHA
        ↓
DEVOLVENDO_CARGA
        ↓
ESCOLHENDO_DESTINO
```

Fluxo de bloqueio:

```text
AGUARDANDO_SENHA
        ↓
3 tentativas incorretas
        ↓
SISTEMA_BLOQUEADO
        ↓
código de manutenção
        ↓
AGUARDANDO_SENHA
```

---

# 28. Estados do sistema

### `ESCOLHENDO_DESTINO`

O robô está parado aguardando a seleção da estação de destino.

### `AGUARDANDO_CARGA`

O compartimento está aberto aguardando a colocação da carga.

### `MOSTRANDO_SENHA`

A senha da viagem foi gerada e está sendo apresentada ao usuário.

### `DEVOLVENDO_CARGA`

A viagem foi cancelada depois que a carga foi colocada.

### `MANOBRA_INICIAL`

O robô executa a curva necessária antes de iniciar o deslocamento.

### `SAINDO_DA_ORIGEM`

O robô deixa a marca da estação inicial.

### `EM_VIAGEM`

O robô realiza o seguimento da linha e monitora obstáculos e estações.

### `AGUARDANDO_SENHA`

O robô chegou ao destino e aguarda a autenticação.

### `PORTA_ABERTA`

A senha foi validada e o usuário pode retirar a carga.

### `SISTEMA_BLOQUEADO`

O limite de tentativas foi atingido e o sistema aguarda o procedimento de manutenção.

---

# 29. Proteção contra obstáculos durante a navegação

A verificação de obstáculos possui prioridade sobre o seguimento de linha.

A lógica durante o deslocamento é:

```text
Verificar obstáculo
       ↓
Existe obstáculo?
   ↙          ↘
 SIM          NÃO
 ↓             ↓
Parar       Seguir linha
 ↓             ↓
Aguardar     Verificar estação
```

Se o obstáculo permanecer por aproximadamente:

```text
2 segundos
```

o LCD apresenta:

```text
OBSTACULO NA VIA
```

Esse aviso possui função visual e não altera a lógica de navegação.

Quando o caminho é liberado, o sistema retorna à indicação normal da viagem.

---

# 30. Inicialização

Durante o `setup()`, o firmware:

1. configura os pinos dos motores;
2. configura os sensores ultrassônicos;
3. configura o sensor digital de estação;
4. inicia o barramento I²C;
5. configura o I²C em 400 kHz;
6. inicializa o LCD;
7. desliga os LEDs;
8. para os motores;
9. fecha o compartimento;
10. define a estação inicial como A;
11. define a orientação inicial como Norte;
12. inicializa o gerador aleatório;
13. apresenta a tela inicial.

A condição inicial é:

```text
Estação = A
Orientação = Norte
```

---

# 31. Pinagem completa

| Pino | Função |
| ---- | --- |
| D0 | Livre |
| D1 | Livre |
| D2 | Servo |
| D3 | TRIG ultrassônico direito  |
| D4 | Sensor digital de estação  |
| D5 | PWM motor esquerdo |
| D6 | PWM motor direito |
| D7 | Direção motor esquerdo |
| D8 | Direção motor esquerdo |
| D9 | Direção motor direito |
| D10  | Direção motor direito |
| D11  | TRIG ultrassônico esquerdo |
| D12  | ECHO ultrassônico esquerdo |
| D13  | ECHO ultrassônico direito  |
| A0 | LDR linha esquerdo |
| A1 | LDR linha central |
| A2 | LDR linha direito |
| A3 | LDR estação esquerdo |
| A4 | SDA |
| A5 | SCL |

---

# 32. Parâmetros principais

| Parâmetro | Valor |
| --- | ---: |
| Velocidade dos motores | 128 |
| Limiar LDR de linha | 300 |
| Limiar LDR de estação | 100 |
| Distância de obstáculo | 30 cm |
| Timeout ultrassônico | 30 ms |
| Intervalo das leituras ultrassônicas |  100 ms |
| Intervalo de leitura do teclado | 50 ms |
| Tempo de curva |  700 ms |
| Tempo da manobra U | 1400 ms |
| Tempo de movimentação do servo |  500 ms |
| Máximo de tentativas da senha | 3 |
| Endereço LCD |  `0x27` |
| Endereço PCF8574 |  `0x20` |
| Endereço Arduino 2 |  `0x10` |
| Frequência I²C | 400 kHz |

---

# 33. Organização do firmware

O firmware principal está dividido logicamente em módulos:

```text
Configuração de pinos
        ↓
Configurações
        ↓
Direções e manobras
        ↓
Máquina de estados
        ↓
Interface LCD
        ↓
Controle dos motores
        ↓
Seguidor de linha
        ↓
Detecção de estação
        ↓
Sensores ultrassônicos
        ↓
Servo
        ↓
LEDs / PCF8574
        ↓
Navegação
        ↓
Teclado / I²C
        ↓
Senhas
        ↓
Máquina de estados
        ↓
setup()
        ↓
loop()
```

Essa organização facilita a manutenção do código e separa as responsabilidades de cada subsistema.

---

# 34. Relação entre eletrônica e software

O funcionamento do robô depende da integração entre sensores, atuadores e software.

```text
             ┌──────────────┐
             │   SENSORES   │
             └──────┬───────┘
                    ↓
             ┌──────────────┐
             │   ARDUINO    │
             │   PRINCIPAL  │
             └──────┬───────┘
                    ↓
       ┌────────────┼────────────┐
       ↓            ↓            ↓
    MOTORES       SERVO       PCF8574
       ↓            ↓            ↓
   Movimento    Compart.      LEDs
       
                    ↕
                 I²C
                    ↕
             ┌──────────────┐
             │  ARDUINO 2   │
             └──────┬───────┘
                    ↓
               TECLADO 4×4
```

O Arduino principal integra as informações dos sensores com a máquina de estados e determina as ações do robô.

---

# 35. Arquivos relacionados

O firmware do projeto está separado em dois arquivos:

```text
arduino/
├── mestre/
│   └── mestre.ino
└── escravo/
    └── escravo.ino
```

O arquivo `mestre.ino` contém a lógica principal do robô.

O arquivo `escravo.ino` contém a implementação do Arduino responsável pelo teclado.

A simulação eletrônica complementar foi desenvolvida no **Tinkercad Circuits**.

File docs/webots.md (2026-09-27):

# Simulação no Webots

## 1. Visão geral

A simulação do **ROBÔ ENTREGADOR** foi desenvolvida utilizando o **Webots**, com o objetivo de representar virtualmente o comportamento do robô e o ambiente no qual ele deverá operar.

A utilização da simulação complementa as outras duas frentes do protótipo:

```text
Eletrônica
     +
Modelagem mecânica
     +
Simulação
```

Enquanto a eletrônica representa o sistema de controle e seus componentes, e o OpenSCAD representa a estrutura mecânica, o Webots permite representar o comportamento do robô em um ambiente virtual.

---

## 2. Objetivo da simulação

A simulação foi desenvolvida para representar o conceito de um robô móvel realizando deslocamentos entre diferentes pontos.

No contexto do projeto, o ambiente utilizado representa o **Centro de Tecnologia (CT) da Universidade Federal do Ceará (UFC)**.

A simulação permite visualizar uma representação virtual do ambiente e desenvolver o comportamento de navegação antes da construção de uma versão física completa.

---

## 3. Organização dos arquivos

Os arquivos relacionados ao Webots estão organizados no repositório da seguinte forma:

```text
webots/
├── controllers/
│   └── rota_3_pontos/
│       └── rota_3_pontos.py
│
└── worlds/
    ├── textures/
    │   └── centro_de_tecnologia.jpg
    ├── .criar.jpg
    ├── .criar.wbproj
    └── criar.wbt
```

Essa organização mantém os arquivos da simulação separados das demais partes do projeto.

---

## 4. Mundo da simulação

O mundo principal utilizado na simulação está localizado em:

```text
webots/worlds/criar.wbt
```

O arquivo `.wbt` contém a definição do ambiente utilizado pelo Webots.

A estrutura do mundo está associada à representação do ambiente do Centro de Tecnologia utilizada no projeto.

---

## 5. Representação do Centro de Tecnologia

A simulação utiliza uma textura referente ao Centro de Tecnologia:

```text
webots/worlds/textures/centro_de_tecnologia.jpg
```

Essa textura é utilizada como parte da representação visual do ambiente.

A utilização de uma representação do CT aproxima a simulação do cenário proposto para a aplicação real do robô.

---

## 6. Controlador

O projeto possui um controlador desenvolvido em Python:

```text
webots/controllers/rota_3_pontos/rota_3_pontos.py
```

O controlador é responsável pela lógica executada pelo robô dentro do ambiente de simulação.

O nome `rota_3_pontos` está relacionado à rota representada nessa etapa do desenvolvimento da simulação.

---

## 7. Relação entre simulação e projeto

A simulação representa uma etapa intermediária entre o conceito do robô e uma implementação física completa.

O desenvolvimento pode ser representado por:

```text
CONCEITO
   ↓
Definição do robô entregador
   ↓
PROTÓTIPO
   ├── Eletrônica
   ├── Mecânica
   └── Software
   ↓
SIMULAÇÃO
   ↓
Webots
   ↓
Validação e desenvolvimento do comportamento
   ↓
Futura implementação física
```

Essa abordagem permite desenvolver diferentes partes do projeto de forma independente antes da construção de um robô físico completo.

---

## 8. Ambiente virtual

O ambiente virtual foi desenvolvido para representar o cenário de operação do projeto.

A utilização do Webots permite trabalhar com uma representação tridimensional do ambiente e associar um controlador ao robô simulado.

O mundo utilizado pelo projeto é:

```text
criar.wbt
```

e o controlador associado está localizado em:

```text
controllers/rota_3_pontos/rota_3_pontos.py
```

---

## 9. Relação com a navegação

A navegação é uma das principais funções do ROBÔ ENTREGADOR.

No protótipo em Arduino, a navegação está relacionada ao seguimento da linha, identificação das estações, orientação do robô e detecção de obstáculos.

No Webots, o objetivo é representar o comportamento de deslocamento do robô dentro de um ambiente virtual.

Assim, as duas abordagens fazem parte do mesmo conceito geral:

```text
Protótipo Arduino
        ↓
Controle e navegação
        ↓
Robô físico

Webots
        ↓
Simulação do comportamento
        ↓
Robô virtual
```

---

## 10. Evolução do protótipo

A utilização do Webots faz parte da estratégia adotada pelo projeto para lidar com a limitação de tempo da etapa de desenvolvimento.

Construir e testar um robô físico completo capaz de navegar pelo Centro de Tecnologia em aproximadamente duas semanas representaria uma tarefa de grande complexidade.

Por isso, o projeto foi dividido em diferentes níveis de prototipagem:

### Eletrônica

Simulação dos componentes e da lógica de controle utilizando Arduino e Tinkercad.

### Mecânica

Modelagem do chassi e do compartimento de carga utilizando OpenSCAD.

### Simulação

Representação do ambiente e do comportamento do robô utilizando Webots.

Essa divisão permite desenvolver e demonstrar diferentes aspectos do projeto sem depender da construção imediata de uma versão física completa.

---

## 11. Arquivos da simulação

Os principais arquivos relacionados ao Webots são:

| Arquivo | Função |
| --- | --- |
| `webots/worlds/criar.wbt` | Mundo principal da simulação  |
| `webots/worlds/textures/centro_de_tecnologia.jpg` | Textura utilizada no ambiente |
| `webots/controllers/rota_3_pontos/rota_3_pontos.py` | Controlador da simulação |
| `webots/worlds/.criar.wbproj` | Arquivo de projeto do Webots  |

Também estão presentes arquivos auxiliares utilizados pelo projeto do mundo.

---

## 12. Organização do repositório

A separação dos arquivos do Webots dentro da pasta `webots/` facilita a organização do repositório:

```text
robo-entregador/
│
├── arduino/
│   ├── mestre/
│   └── escravo/
│
├── openscad/
│   └── chassi.scad
│
├── webots/
│   ├── controllers/
│   │   └── rota_3_pontos/
│   │       └── rota_3_pontos.py
│   │
│   └── worlds/
│       ├── textures/
│       │   └── centro_de_tecnologia.jpg
│       └── criar.wbt
│
└── docs/
    ├── eletronica.md
    ├── mecanica.md
    ├── software.md
    └── webots.md
```

Essa estrutura separa claramente as três principais frentes técnicas do protótipo.

---

## 13. Relação entre as ferramentas

Cada ferramenta utilizada no projeto possui uma finalidade específica:

| Ferramenta | Aplicação |
| --- | --- |
| Tinkercad Circuits | Simulação da eletrônica |
| Arduino / C++ | Controle do protótipo eletrônico |
| OpenSCAD | Modelagem mecânica |
| Webots | Simulação do robô e do ambiente |
| Python | Controlador da simulação do Webots |
| GitHub | Organização e documentação do projeto |

Essa divisão permite que diferentes aspectos do sistema sejam desenvolvidos e documentados separadamente.

---

## 14. Contribuição do Webots para o projeto

A simulação contribui para o desenvolvimento do projeto ao fornecer uma representação virtual do ambiente de operação.

Ela também permite que o comportamento de navegação seja desenvolvido em paralelo à eletrônica e à modelagem mecânica.

Dessa forma, o Webots funciona como uma etapa de prototipagem e experimentação dentro do desenvolvimento do ROBÔ ENTREGADOR.

---

## 15. Limitações da simulação

A simulação não deve ser interpretada como uma reprodução completa de todos os aspectos físicos do robô real.

Ela representa uma etapa de desenvolvimento destinada a estudar e demonstrar o comportamento do sistema em um ambiente virtual.

Diferenças entre a simulação e uma implementação física podem surgir em aspectos como:

* sensores reais;
* atrito;
* motores;
* alimentação elétrica;
* tolerâncias mecânicas;
* ruído de sensores;
* comportamento físico dos componentes.

Por isso, os resultados da simulação devem ser considerados parte do processo de prototipagem e não uma substituição completa dos testes físicos.

---

## 16. Próximas etapas

A partir das três frentes desenvolvidas, uma evolução natural do projeto seria integrar:

```text
Modelo mecânico
       +
Eletrônica
       +
Firmware
       +
Navegação
       +
Simulação
       ↓
Protótipo físico
```

Uma futura versão poderia utilizar o modelo mecânico desenvolvido no OpenSCAD como base para a construção física do robô, mantendo a arquitetura eletrônica e a lógica de controle desenvolvidas durante o projeto.

---

## 17. Arquivos relacionados

Os arquivos da simulação estão disponíveis em:

```text
webots/
```

Controlador:

```text
webots/controllers/rota_3_pontos/rota_3_pontos.py
```

Mundo:

```text
webots/worlds/criar.wbt
```

Textura:

```text
webots/worlds/textures/centro_de_tecnologia.jpg
```

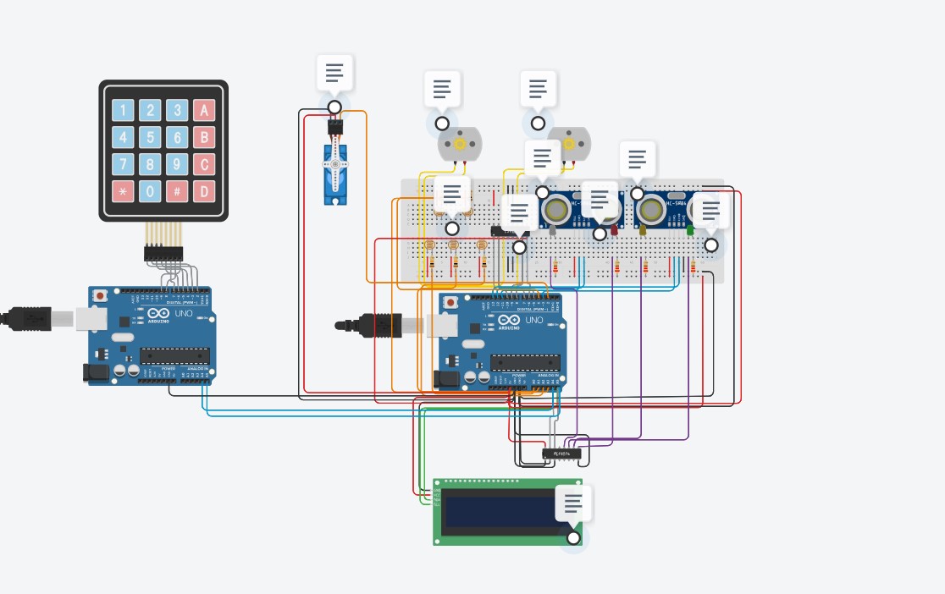
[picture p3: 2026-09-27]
media/images/tinkercad/Captura de tela 2026-09-27 201842.jpg

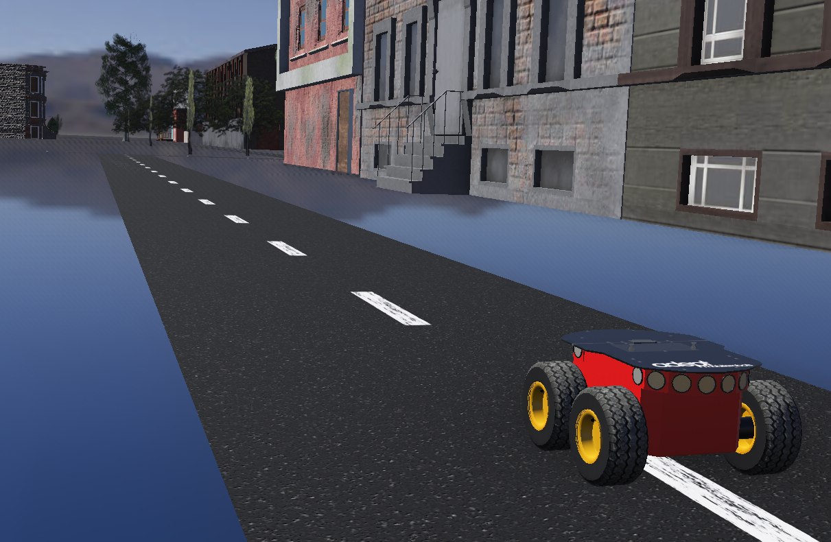
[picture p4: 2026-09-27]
media/images/webots/photo_5030813907160862120_y.jpg

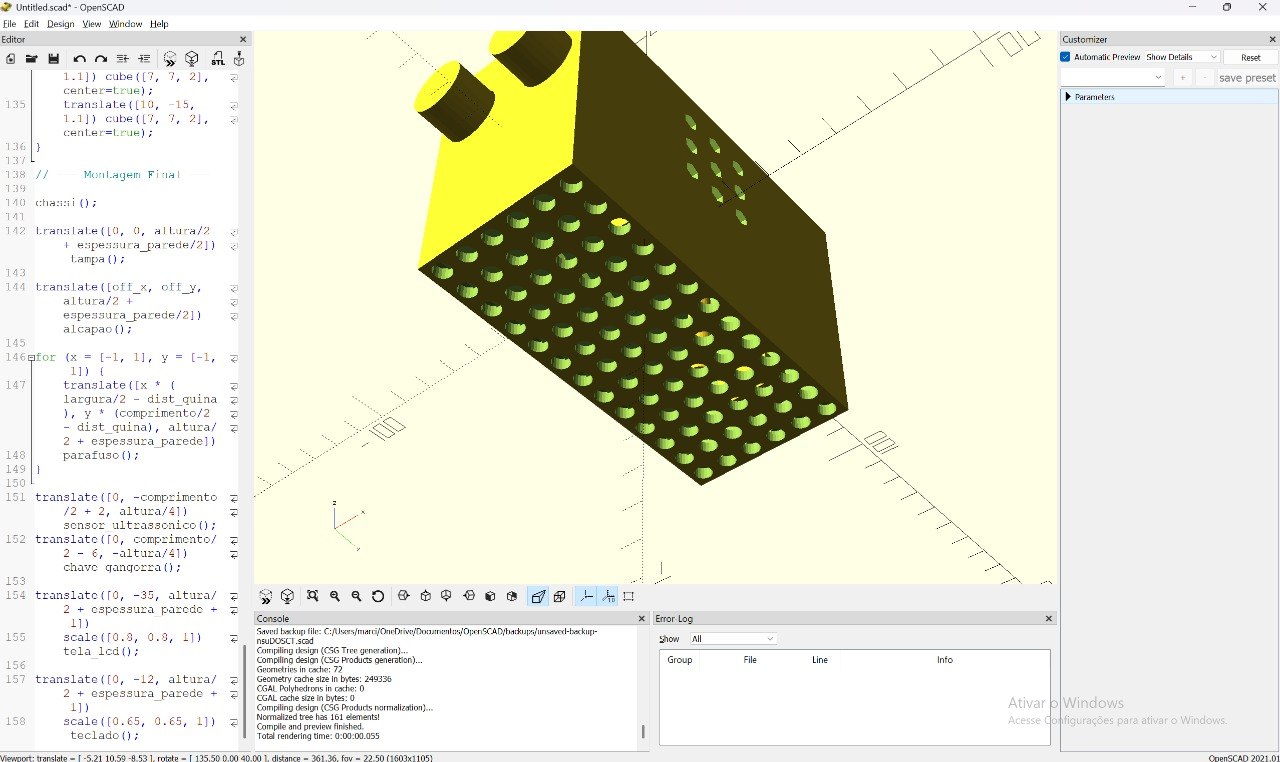
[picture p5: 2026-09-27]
media/images/openscad/photo_5022031515084327989_y.jpg

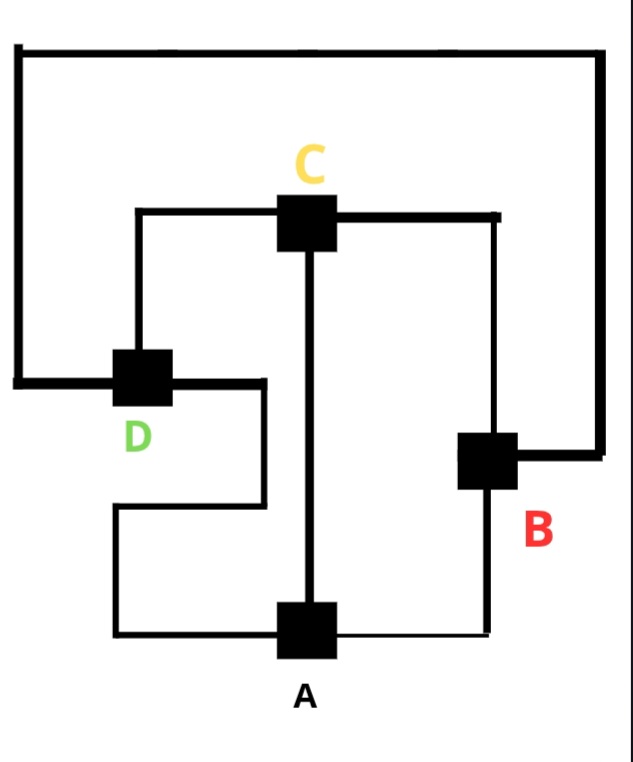
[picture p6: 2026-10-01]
media/images/tinkercad/Screenshot_20261001_085805_Chrome.jpg

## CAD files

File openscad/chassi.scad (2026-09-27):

// Dimensões Principais (Base Lego 6x13 + Abas de fixação baixas)
espessura_parede = 3;
largura = 48;       
comprimento = 104;  
altura = 65;        
dist_quina = 4;     
raio_parafuso = 1.6;

module chassi() {
    union() {
        difference() {
            // Corpo principal + Abas laterais apenas na base (5mm de altura)
            union() {
                cube([largura, comprimento, altura], center=true);
                // Aba com 5mm de altura, alinhada com o chão (Z = -altura/2 + 2.5)
                translate([0, -40, -altura/2 + 2.5]) cube([largura + 16, 24, 5], center=true);
            }
            
            // Interior oco
            translate([0, 0, espessura_parede])
                cube([largura - espessura_parede*2, comprimento - espessura_parede*2, altura], center=true);
                
            // Encaixes Lego (Fundo matriz 6x13 principal)
            for (x = [-largura/2 + 4 : 8 : largura/2 - 4], y = [-comprimento/2 + 4 : 8 : comprimento/2 - 4]) {
                translate([x, y, -altura/2 + 1])
                    cylinder(h=espessura_parede + 2, r=2.5, $fn=20, center=true);
            }
            
            // Encaixes Lego Extras (Nas abas de 5mm, 3 primeiras fileiras)
            for (x = [-largura/2 - 4, largura/2 + 4]) {
                for (y = [-48, -40, -32]) {
                    translate([x, y, -altura/2 + 1])
                        cylinder(h=espessura_parede + 2, r=2.5, $fn=20, center=true);
                }
            }
            
            // Furos: Sensor ultrassônico e Chave gangorra
            translate([0, -comprimento/2, altura/4]) rotate([90, 0, 0]) {
                translate([-13, 0, 0]) cylinder(h=20, r=8.2, $fn=50, center=true);
                translate([ 13, 0, 0]) cylinder(h=20, r=8.2, $fn=50, center=true);
            }
            translate([0, comprimento/2, -altura/4]) cube([15, 20, 10], center=true);
            
            // Respiros laterais
            for (y_off = [-10, 0, 10], z_off = [5, 15, 25], x_off = [-largura/2, largura/2]) {
                translate([x_off, y_off, z_off]) rotate([0, 90, 0]) cylinder(h=20, r=2.5, $fn=6, center=true);
            }
            
            // Furos da tampa nas quinas
            for (x = [-1, 1], y = [-1, 1]) {
                translate([x * (largura/2 - dist_quina), y * (comprimento/2 - dist_quina), altura/2 - 10])
                    cylinder(h=25, r=raio_parafuso, $fn=20);
            }
        }
        
        // Torres de fixação internas
        for (x = [-1, 1], y = [-1, 1]) {
            translate([x * (largura/2 - dist_quina), y * (comprimento/2 - dist_quina), altura/2 - 15])
            difference() {
                cylinder(h=30, r=dist_quina, $fn=30, center=true);
                cylinder(h=32, r=raio_parafuso, $fn=20, center=true);
            }
        }
    }
}

// --- Submódulos da Tampa e Alçapão ---
largura_alc = 26; 
comp_alc = 35; 
altura_alc = 15; 
off_x = 0;   
off_y = 18;  

module tampa() {
    difference() {
        union() {
            // A tampa volta a ser um retângulo limpo
            cube([largura, comprimento, espessura_parede], center=true);
            
            translate([off_x, off_y, -altura_alc/2 - espessura_parede/2])
            difference() {
                cube([largura_alc, comp_alc, altura_alc], center=true);
                translate([0, 0, espessura_parede])
                    cube([largura_alc - espessura_parede*2, comp_alc - espessura_parede*2, altura_alc], center=true);
            }
        }
        
        translate([off_x, off_y, 0])
            cube([largura_alc - espessura_parede*2, comp_alc - espessura_parede*2, espessura_parede + 2], center=true);
            
        for (x = [-1, 1], y = [-1, 1]) {
            translate([x * (largura/2 - dist_quina), y * (comprimento/2 - dist_quina), 0])
                cylinder(h=espessura_parede + 2, r=raio_parafuso + 0.4, $fn=20, center=true);
        }
    }
}

module alcapao() {
    espessura = 1.2; 
    porta_w = largura_alc - espessura_parede*2 - 0.6; 
    porta_l = comp_alc - espessura_parede*2 - 0.6;
    
    union() {
        cube([porta_w + 4, porta_l + 4, espessura], center=true);
        translate([0, 0, -espessura]) cube([porta_w, porta_l, espessura], center=true);
        
        translate([0, porta_l/2 - 4, espessura])
        difference() {
            cube([4, 6, 6], center=true);
            translate([0, 0, 1]) rotate([0, 90, 0]) cylinder(h=10, r=1.5, $fn=15, center=true);
        }
    }
}

// --- Peças Eletrônicas Detalhadas e Parafusos ---

module parafuso() {
    translate([0, 0, 1]) cylinder(h=2, r=3, $fn=20, center=true);
    translate([0, 0, -4]) cylinder(h=10, r=raio_parafuso, $fn=20, center=true);
}

module sensor_ultrassonico() {
    translate([0, 0, 0]) cube([45, 2, 20], center=true);
    translate([-13, -7, 0]) rotate([90, 0, 0]) cylinder(h=14, r=8, $fn=30, center=true);
    translate([ 13, -7, 0]) rotate([90, 0, 0]) cylinder(h=14, r=8, $fn=30, center=true);
    translate([0, 1, -5]) cube([4, 4, 3], center=true);
    translate([0, 1, -9]) cube([8, 2, 4], center=true);
}

module chave_gangorra() {
    cube([16, 12, 11], center=true); 
    translate([0, 6.5, 0]) cube([18, 2, 13], center=true);
    translate([0, 7.5, 0]) rotate([-10, 0, 0]) cube([12, 3, 9], center=true);
}

module tela_lcd() {
    cube([40, 20, 2], center=true);
    translate([0, 0, 1]) cube([36, 16, 2], center=true);
    translate([0, 0, 1.5]) cube([32, 12, 1.5], center=true);
    translate([0, 0, 2.3]) linear_extrude(1) text("***8", size=6, halign="center", valign="center");
}

module teclado() {
    cube([30, 40, 2], center=true);
    for (cx = [-10, 0, 10], cy = [-15, -5, 5, 15]) {
        translate([cx, cy, 1]) cube([7, 7, 2], center=true);
    }
    translate([-10, -15, 1.1]) cube([7, 7, 2], center=true);
    translate([10, -15, 1.1]) cube([7, 7, 2], center=true);
}

// --- Montagem Final ---

chassi();

translate([0, 0, altura/2 + espessura_parede/2]) tampa();

translate([off_x, off_y, altura/2 + espessura_parede/2]) alcapao();

for (x = [-1, 1], y = [-1, 1]) {
    translate([x * (largura/2 - dist_quina), y * (comprimento/2 - dist_quina), altura/2 + espessura_parede])
    parafuso();
}

translate([0, -comprimento/2 + 2, altura/4]) sensor_ultrassonico();
translate([0, comprimento/2 - 6, -altura/4]) chave_gangorra();

translate([0, -35, altura/2 + espessura_parede + 1]) 
    scale([0.8, 0.8, 1]) tela_lcd();

translate([0, -12, altura/2 + espessura_parede + 1]) 
    scale([0.65, 0.65, 1]) teclado();

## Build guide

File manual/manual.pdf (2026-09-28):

# Robô

# Entregador V4

## Manual de operação da simulação

Tinkercad Circuits • Arduino Uno

Este manual explica como usar o arquivo de simulação já montado:
o que cada parte faz, como iniciar, como fazer uma entrega completa e como reproduzir na tela os sensores que, no robô real, dependem do chão e dos objetos.

Não trata da montagem do circuito.

Setembro de 2026

Robô Entregador V4 | Manual de operação da simulação

# Sumário

1 Apresentação | 3
2 Como o circuito funciona | 3
3 Antes de começar | 6
4 Operando a simulação | 7
5 Simulando a pista | 9
6 Senha e bloqueio | 12
7 Referência rápida | 13
8 Problemas comuns | 15

# 1 Apresentação

O Robô Entregador V4 leva uma carga de uma estação a outra. Existem quatro estações, identificadas pelas letras A, B, C e D. Quem usa escolhe o destino no teclado, coloca a carga no compartimento e recebe uma senha de quatro dígitos. O robô segue a linha do percurso até a estação de destino, para, e só abre o compartimento quando a senha correta é digitada. Três senhas erradas seguidas bloqueiam o sistema até que seja informado um código de manutenção.

## 1.1 O que este manual cobre

O arquivo do Tinkercad já está montado e programado. Aqui está o que é preciso para usá-lo:

- o que cada componente faz e como eles se conversam;
- como iniciar a simulação e o que aparece no display;
- o passo a passo de uma entrega, do teclado até a retirada da carga;
- como controlar, com o mouse, os sensores de linha, de estação e de obstáculo;
- o que fazer quando algo não responde.

Leia antes No Tinkercad o robô não anda pela tela. Os motores giram, mas a posição do robô não muda. Quem faz o papel do chão é você: cada sensor de luz representa um ponto da pista, e o valor de luminosidade que você define nele diz ao programa o que o robô estaria vendo. A seção 5 explica como fazer isso.

## 1.2 Visão do circuito

A figura 1 mostra o arquivo aberto no Tinkercad. O Arduino da esquerda lê o teclado. O da direita comanda todo o restante.

# 2 Como o circuito funciona

## 2.1 Blocos principais

O sistema usa dois Arduinos Uno. O U4 só cuida do teclado: varre as 16 teclas e guarda a última pressionada. O U1 é o controlador do robô. Ele pede a tecla ao U4 a cada 50 ms e usa o mesmo barramento de dois fios (I2C) para falar com o display e com os LEDs.

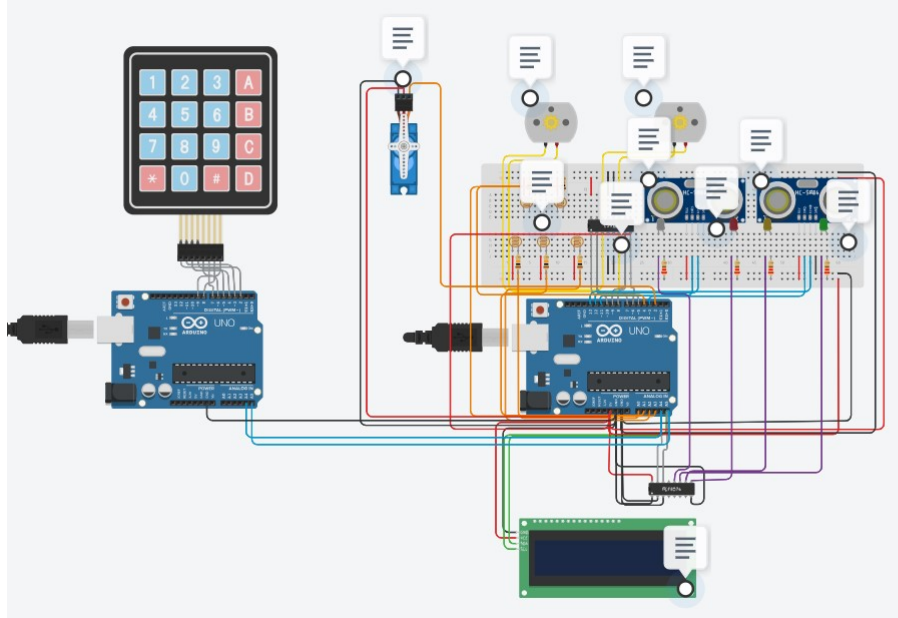
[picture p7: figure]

Figura 1: Circuito completo no Tinkercad.

## 2.2 Etapas de uma entrega

O programa do U1 funciona como uma sequência de etapas. A cada momento o robô está em uma delas, e o teclado só é lido nas etapas em que há interação com o usuário.

1. Escolha do destino. O display mostra a estação atual e pede uma letra.
2. Carga. O servo abre o compartimento; após a confirmação, fecha.
3. Senha da viagem. O programa sorteia quatro dígitos e mostra no display.
4. Manobra inicial. Se o robô não estiver virado para o lado certo, gira no lugar.
5. Saída da origem. Segue a linha até deixar a marca da estação.
6. Viagem. Segue a linha, para diante de obstáculos e procura a marca do destino.
7. Chegada. Para, apaga o LED e pede a senha.
8. Entrega. Com a senha certa o servo abre; com três erros, o sistema trava.

## 2.3 Lista de componentes

A tabela reúne o que está no arquivo, com os nomes que aparecem no esquema elétrico.

Componente | Qtd. | Função no projeto
Arduino Uno R3 (U1) | 1 | Controlador principal: motores, sensores, display, servo e LEDs.
Arduino Uno R3 (U4) | 1 | Lê o teclado e entrega a tecla ao U1 pelo I2C (endereço 0x10).
Teclado 4 × 4 (KEYPAD1) | 1 | Entrada do usuário: destino, confirmação, senha.
Display LCD 16 × 2 I2C | 1 | Mostra mensagens ao usuário (endereço 0x27).

Componente | Qtd. | Função no projeto
Expansor I2C de 8 portas (U2) | 1 | Comanda os LEDs de destino (endereço 0x20).
LEDs (D1 a D4) | 4 | Branco (A), vermelho (B), amarelo (C) e verde (D). Indicam o destino durante a viagem.
Resistores de 220 Ω (R11 a R14) | 4 | Limitam a corrente dos LEDs.
Ponte H L293D (U3) | 1 | Aciona os dois motores com direção e velocidade.
Motores DC (M1, M2) | 2 | Tração do robô.
Fotorresistores (R1, R3, R5, R7, R10) | 5 | Três formam o seguidor de linha; dois detectam a marca de estação.
Resistores de 10 kΩ (R2, R4, R6, R8, R9) | 5 | Um para cada fotorresistor, formando o divisor de tensão.
Sensor ultrassônico HC-SR04 (DIST1, DIST2) | 2 | Detectam obstáculos à frente.
Micro servo posicional (SERVO1) | 1 | Abre e fecha o compartimento da carga.
Protoboard | 1 | Base das ligações do U1.

## 2.4 Ligações do Arduino principal (U1)

Função | Pino | Observação
Motor esquerdo, direção | D7, D8 | Entradas da ponte H.
Motor esquerdo, velocidade | D5 | Sinal PWM.
Motor direito, direção | D9, D10 | Entradas da ponte H.
Motor direito, velocidade | D6 | Sinal PWM.
Seguidor de linha | A0, A1, A2 | Esquerda, centro e direita.
Sensores de estação | A3 e D4 | A3 é analógico (esquerda); D4 é digital (direita).
Ultrassônico 1 | D11 (TRIG), D12 (ECHO)
Ultrassônico 2 | D3 (TRIG), D13 (ECHO)
Servo da tampa | D2 | 0 ◦ fechado, 90◦ aberto.
I2C (SDA, SCL) | A4, A5 | Display, LEDs e teclado.

No Arduino do teclado (U4), as linhas da matriz ficam nos pinos D2 a D5, as colunas em D6 a D9, e A4/A5 seguem para o barramento I2C.

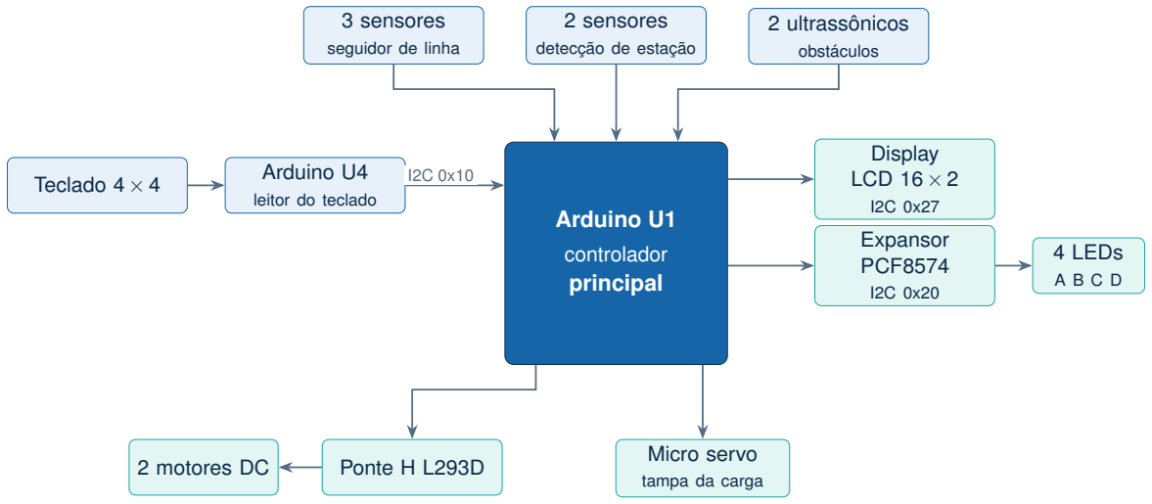
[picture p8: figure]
Arduino U1; controlador principal; Arduino U4; leitor do teclado; Teclado 4 × 4; 3 sensores; seguidor de linha; 2 sensores; detecção de estação; 2 ultrassônicos; obstáculos; Display LCD 16 × 2; Expansor PCF8574; 4 LEDs; 2 motores DC; Ponte H L293D; Micro servo; tampa da carga

Figura 2: Diagrama de blocos. As setas indicam o sentido da informação.

# 3 Antes de começar

## 3.1 Iniciar a simulação

1. Abra o arquivo ROBÔ ENTREGADOR V4 no Tinkercad Circuits.
2. Clique em Iniciar simulação, no canto superior direito.

### 3. Aguarde cerca de um segundo. O servo se posiciona em 0◦

(o display mostra brevemente FECHANDO...) e a tela de escolha de destino aparece.

ORIGEM: A

DESTINO? (A-D)

A partir daí o robô considera que está na estação A, virado para o norte. Sempre que você parar e iniciar a simulação de novo, ele volta para esse ponto.

## 3.2 O que você vai usar com o mouse

Com a simulação rodando, alguns componentes respondem ao clique:

Componente | Como interagir
Teclado 4 × 4 | Clique nas teclas, uma de cada vez.
Fotorresistores | Clique no componente: aparece um controle deslizante de luminosidade. Arraste para claro ou escuro.
Sensores ultrassônicos | Clique no sensor: aparece um objeto ou um campo de distância. Arraste o objeto ou digite o valor, em centímetros.
Display, LEDs, servo e motores | Só observação. Mostram o resultado do que você fez.

Dica Uma tecla por vez, e espere a tela reagir antes de clicar na próxima. O Arduino do teclado guarda apenas uma tecla até o U1 buscá-la, então cliques muito rápidos podem se perder.

## 3.3 O teclado

1 | 2 | 3 | A
4 | 5 | 6 | B
7 | 8 | 9 | C
* | 0 | # | D

As letras escolhem a estação, os números formam a senha, # confirma e * volta ou apaga. O que cada tecla faz depende da tela em que o robô está; a tabela completa está na seção 7.

# 4 Operando a simulação

Este é o ciclo completo de uma entrega. Cada passo traz o que aparece no display.

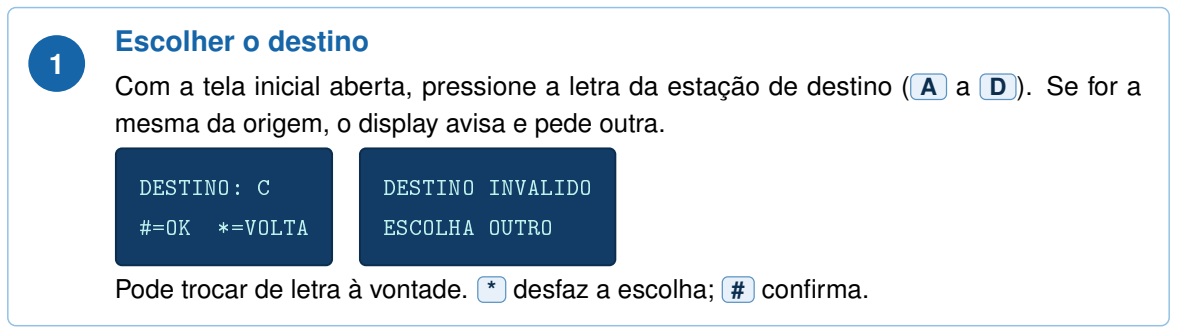
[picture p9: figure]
Escolher o destino; DESTINO: C; *=VOLTA; DESTINO INVALIDO; ESCOLHA OUTRO

Com a tela inicial aberta, pressione a letra da estação de destino ( A a D ). Se for a mesma da origem, o display avisa e pede outra.

Pode trocar de letra à vontade. * desfaz a escolha; # confirma.

Ao confirmar, o servo gira para 90◦ e abre o compartimento. No Tinkercad, é o momento em que você imagina a carga sendo colocada. Depois pressione # ; o servo volta a 0◦ e a

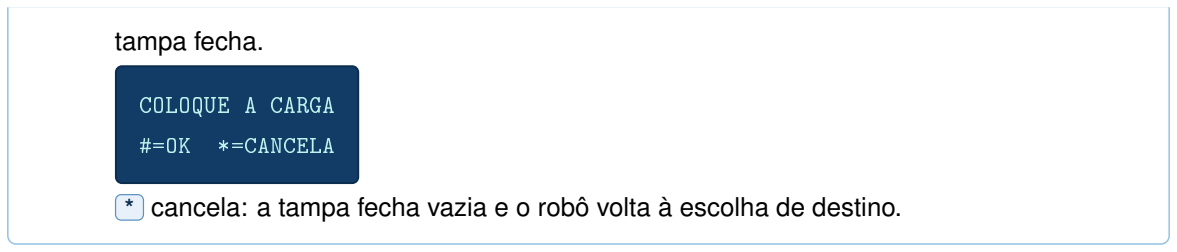
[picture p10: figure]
tampa fecha.; COLOQUE A CARGA; *=CANCELA

* cancela: a tampa fecha vazia e o robô volta à escolha de destino.

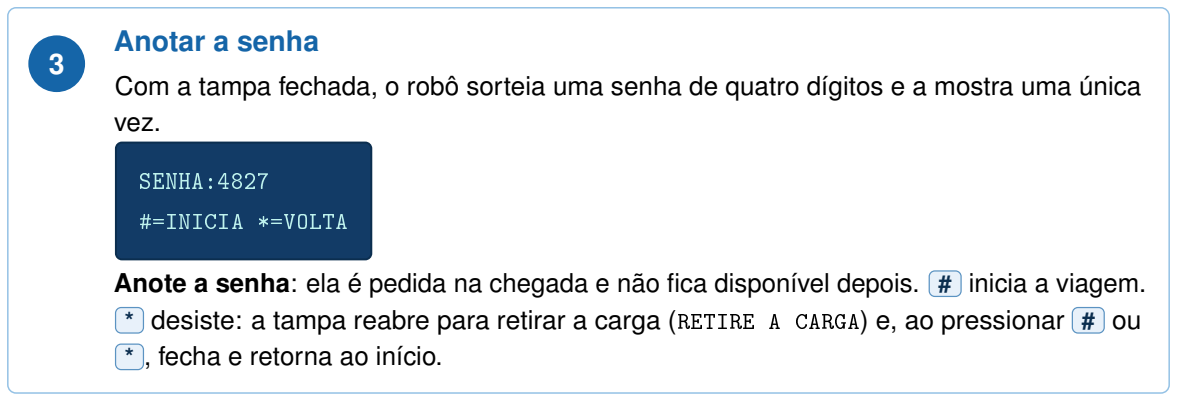
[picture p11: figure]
Anotar a senha; vez.; SENHA:4827; #=INICIA *=VOLTA; * , fecha e retorna ao início.

Com a tampa fechada, o robô sorteia uma senha de quatro dígitos e a mostra uma única

Anote a senha: ela é pedida na chegada e não fica disponível depois. # inicia a viagem. * desiste: a tampa reabre para retirar a carga (RETIRE A CARGA) e, ao pressionar # ou

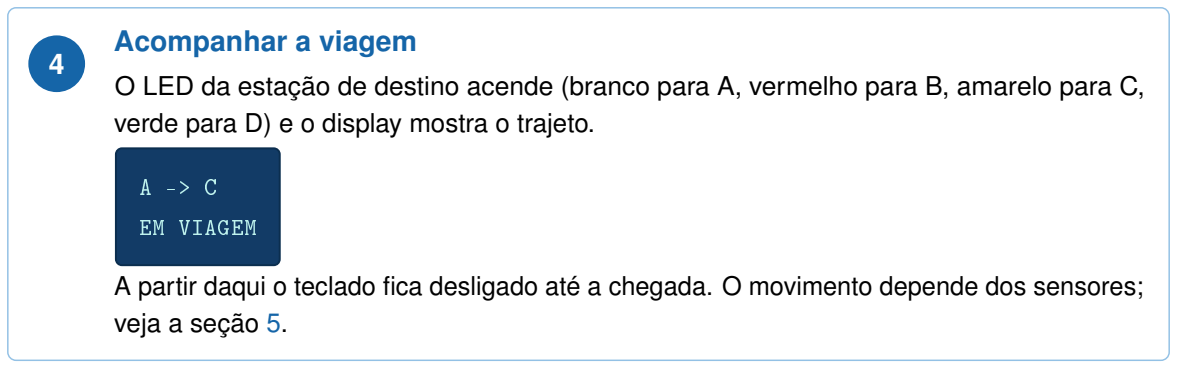
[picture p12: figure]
Acompanhar a viagem; EM VIAGEM; veja a seção 5.

O LED da estação de destino acende (branco para A, vermelho para B, amarelo para C, verde para D) e o display mostra o trajeto.

A partir daqui o teclado fica desligado até a chegada. O movimento depende dos sensores;

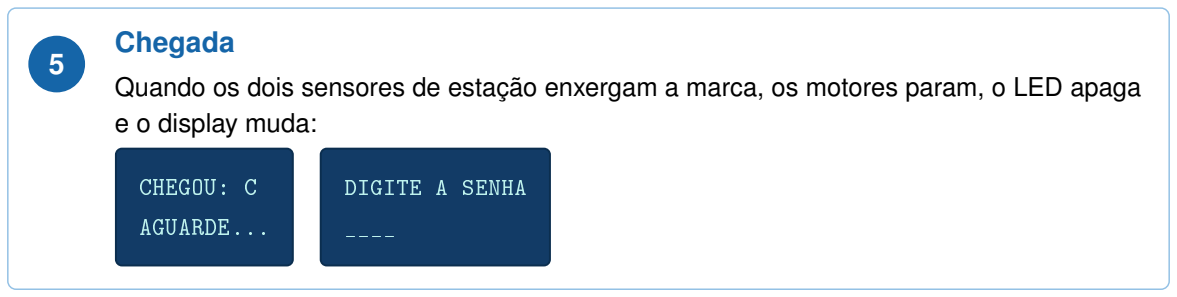
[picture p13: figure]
Chegada; e o display muda:; CHEGOU: C; AGUARDE...; DIGITE A SENHA

Quando os dois sensores de estação enxergam a marca, os motores param, o LED apaga

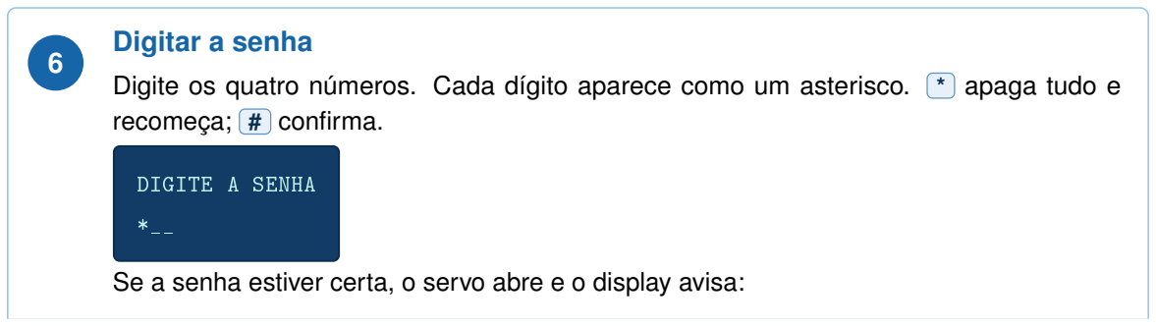
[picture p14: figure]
Digitar a senha; recomeça; # confirma.; DIGITE A SENHA

Digite os quatro números. Cada dígito aparece como um asterisco. * apaga tudo e

Se a senha estiver certa, o servo abre e o display avisa:

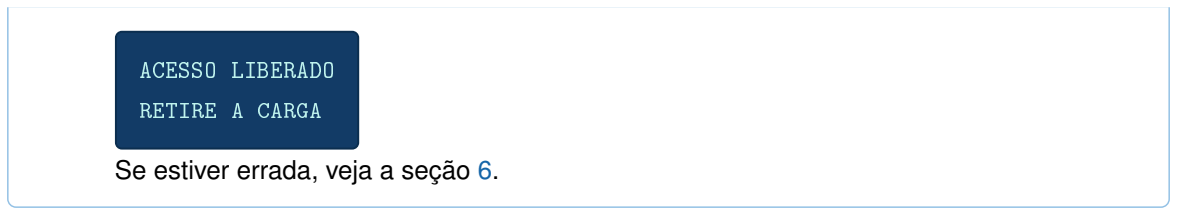
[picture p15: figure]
ACESSO LIBERADO; RETIRE A CARGA; Se estiver errada, veja a seção 6.

Depois de retirar a carga, pressione # ou * . O servo fecha e a tela de destino volta, agora com a estação em que o robô parou como nova origem.

Sequência mais curta Uma entrega sem imprevistos usa estas teclas, na ordem: letra do destino, # , # , # , (viagem), quatro dígitos da senha, # , # .

# 5 Simulando a pista

Depois do passo 3, tudo o que o robô faz depende dos sensores. Os cinco fotorresistores ficam na protoboard: os três da fileira inferior formam o seguidor de linha, e os dois da fileira superior, sob as anotações, são os sensores de estação.

## 5.1 Como o programa interpreta a luz

O programa lê cada fotorresistor como um número de 0 a 1023. Quanto mais escuro o sensor, menor o número. Marcas escuras no chão (a linha e as estações) correspondem a valores baixos.

Sensor | Conta como detectado quando | Na simulação
Linha (esquerda, centro, direita) | leitura abaixo de 300 | Deixe o sensor escuro para “estar sobre a linha”.
Estação, esquerda (A3) | leitura abaixo de 100 | Leve o controle quase ao mínimo.
Estação, direita (D4) | nível digital baixo | Também escuro, no mínimo.

A estação só é reconhecida quando os dois sensores de estação estão escuros ao mesmo tempo.

## 5.2 Seguidor de linha

Cada combinação de sensores escuros faz o robô se comportar de um jeito. Na tabela, E é o sensor da esquerda, C o do centro e D o da direita; “escuro” significa sobre a linha.

E | C | D | Reação dos motores
escuro | claro | claro | Gira para a esquerda.
escuro | escuro | claro | Gira para a esquerda.
claro | escuro | claro | Segue em frente.
claro | escuro | escuro | Gira para a direita.
claro | claro | escuro | Gira para a direita.
escuro | escuro | escuro | Segue em frente.
escuro | claro | escuro | Segue em frente.
claro | claro | claro | Repete o último giro. Se ainda não houve giro, para.

Para ver o robô em frente, deixe apenas o sensor do centro escuro. Para ver uma correção, escureça só o da esquerda ou o da direita e observe o sentido dos motores.

O que os motores mostram

Movimento | Motor esquerdo | Motor direito
Frente | para frente | para frente
Giro à direita | para frente | para trás
Giro à esquerda | para trás | para frente
Parado | parado | parado

Atenção Com os três sensores claros e sem giro anterior, os motores ficam parados. Se a viagem começar e nada girar, deixe ao menos o sensor central escuro.

## 5.3 Chegada à estação

O robô só aceita uma estação depois de ter saído da marca de origem. Por isso, no início da viagem, pelo menos um dos dois sensores de estação precisa estar claro. Na configuração normal isso acontece sozinho e a etapa passa em um instante.

Para simular a chegada, escureça os dois sensores de estação. Os motores param, o LED apaga, o display mostra CHEGOU e a senha é pedida.

## 5.4 Obstáculos

Os dois sensores ultrassônicos vigiam o caminho. Se qualquer um medir menos de 30 cm, o robô para e retoma sozinho quando a distância volta a ser maior.

- Aproxime o objeto para menos de 30 cm: os motores param.
- Depois de cerca de 2 segundos parado, a segunda linha do display avisa:

A -> C

OBSTACULO NA VIA

- Afaste o objeto: o display volta a mostrar EM VIAGEM e o movimento continua de onde parou. Se o robô estava fazendo uma manobra, o tempo parado não conta: ela continua de onde parou.

## 5.5 Manobra inicial

O robô lembra para onde está voltado. Se o caminho até o destino começa em outra direção, ele gira no lugar antes de seguir a linha: cerca de 0,7 s para uma curva de 90◦ e 1,4 s para meia-volta. Na tela,

isso aparece como os dois motores girando em sentidos opostos.

Partindo de A, virado para o norte, as três rotas possíveis são:

Rota | Direção de saída | Manobra
A → B | leste | giro à direita
A → C | norte | nenhuma
A → D | oeste | giro à esquerda

A tabela seguinte mostra a direção de saída e a orientação em que o robô fica ao chegar, para todas as rotas. Ela vale para as viagens seguintes: a manobra necessária depende de como o robô ficou na chegada anterior.

Origem | Destino | Sai para | Chega virado para
A | B | leste | norte
A | C | norte | norte
A | D | oeste | oeste
B | A | sul | oeste
B | C | norte | oeste
B | D | leste | leste
C | A | sul | sul
C | B | leste | sul
C | D | oeste | sul
D | A | leste | leste
D | B | oeste | oeste
D | C | norte | leste

## 5.6 Exemplo completo: A para C

1. Inicie a simulação e pressione C , # , # . Anote a senha mostrada e pressione # .
2. O LED amarelo acende. Como o robô já está virado para o norte, não há manobra.
3. Deixe só o fotorresistor central da linha escuro. Os dois motores giram para frente.

4. Teste uma correção: escureça o da esquerda e observe o giro; volte ao centro.
5. Teste um obstáculo: leve um ultrassônico a 20 cm, espere o aviso e afaste.
6. Escureça os dois sensores de estação. O robô para e o display pede a senha.
7. Digite a senha anotada e pressione # . O servo abre. Pressione # para fechar.

# 6 Senha e bloqueio

## 6.1 Senha errada

A cada erro o display informa quantas tentativas restam e volta à digitação depois de pouco mais de um segundo.

SENHA INCORRETA

RESTAM 2 TENT.

São três tentativas por chegada. Acertar zera a contagem.

## 6.2 Sistema bloqueado

Na terceira senha errada o sistema trava. O display mostra o aviso e, em seguida, pede o código de manutenção.

SISTEMA BLOQ.

COD. MANUTENCAO

COD. MANUTENCAO

***

O código tem quatro dígitos: 1 4 0 8. Digite e confirme com # ; * apaga o que foi digitado.

- Código certo: aparece MANUTENCAO OK / DESBLOQUEADO, as tentativas voltam a três e o robô retorna à digitação da senha. A senha da viagem continua a mesma.
- Código errado: o display mostra CODIGO ERRADO e o campo é limpo para nova tentativa. Não há limite de tentativas nesta etapa.

Atenção A senha da viagem não pode ser consultada depois de mostrada. Se você esquecer, a saída é parar e iniciar a simulação, o que reinicia o robô na estação A.

# 7 Referência rápida

## 7.1 Teclas por tela

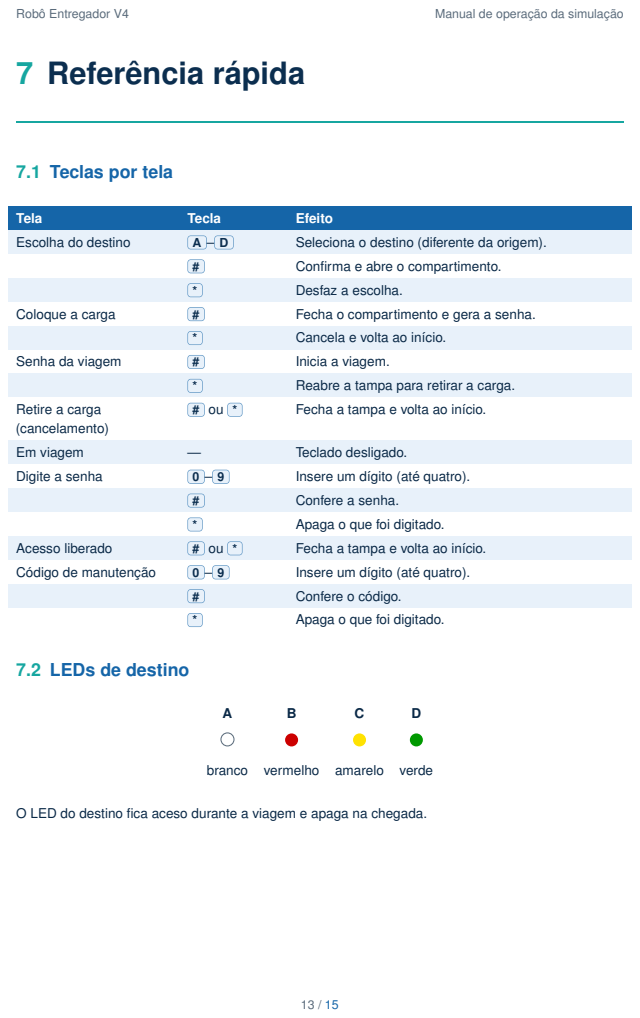
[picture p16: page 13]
branco; vermelho; amarelo; verde

Tela | Tecla | Efeito

Escolha do destino | A – D | Seleciona o destino (diferente da origem).

# | Confirma e abre o compartimento.

* | Desfaz a escolha.

Coloque a carga | # | Fecha o compartimento e gera a senha.

* | Cancela e volta ao início.

Senha da viagem | # | Inicia a viagem.

* | Reabre a tampa para retirar a carga.

Retire a carga (cancelamento) | # ou * | Fecha a tampa e volta ao início.

Em viagem | — | Teclado desligado.

Digite a senha | 0 – 9 | Insere um dígito (até quatro).

# | Confere a senha.

* | Apaga o que foi digitado.

Acesso liberado | # ou * | Fecha a tampa e volta ao início.

Código de manutenção | 0 – 9 | Insere um dígito (até quatro).

# | Confere o código.

7.2 LEDs de destino

O LED do destino fica aceso durante a viagem e apaga na chegada.

## 7.3 Valores do programa

Parâmetro | Valor
Velocidade dos motores | 128 de 255 (cerca de metade)
Limite do seguidor de linha | leitura abaixo de 300
Limite da estação (lado analógico) | leitura abaixo de 100
Distância de parada por obstáculo | 30 cm
Aviso de obstáculo no display | após 2 s parado
Curva de 90◦ / meia-volta | 0,7 s / 1,4 s
Servo fechado / aberto | 0 ◦ / 90◦
Tentativas de senha por chegada | 3
Código de manutenção | 1408
Leitura do teclado | a cada 50 ms

# 8 Problemas comuns

O que acontece | Causa provável | O que fazer
O display está apagado ou vazio | A simulação não foi iniciada. | Clique em Iniciar simulação.
Uma tecla não responde | Clique rápido demais, ou o robô está em viagem ou manobra, quando o teclado não é lido. | Clique com calma, uma tecla por vez. Durante a viagem, espere a chegada.
A tela demora a reagir depois de uma mensagem | Algumas mensagens ficam cerca de um segundo na tela de propósito. | Aguarde e continue.
A viagem começa, mas os motores não giram | Os três sensores de linha estão claros. | Escureça o sensor central da linha.
A chegada não é reconhecida | Só um dos sensores de estação está escuro, ou o valor não é baixo o bastante. | Leve os dois ao mínimo de luminosidade.
O robô fica parado e o display mostra OBSTACULO NA VIA | Algum ultrassônico mede menos de 30 cm. | Afaste os objetos dos dois sensores.
O robô parece nunca deixar a origem | Os dois sensores de estação continuam escuros desde o início. | Clareie ao menos um deles.
A senha não é aceita | Digitada errada ou de outra viagem. | Use a senha mostrada no passo 3 desta viagem.
A tampa não abre ou fecha | O servo só se move nas trocas de tela previstas. | Confira a tela atual e o passo correspondente na seção 7.

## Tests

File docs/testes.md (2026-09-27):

# Testes, Validação e Evolução do Projeto

## 1. Visão geral

O desenvolvimento do ROBÔ ENTREGADOR foi realizado de forma incremental, com a implementação e validação de diferentes módulos antes da integração do sistema completo.

Como o projeto envolvia eletrônica, firmware, modelagem mecânica e simulação, a equipe optou por desenvolver as partes separadamente e posteriormente integrá-las.

Essa estratégia permitiu identificar problemas de hardware, software e arquitetura antes da montagem do sistema completo.

---

## 2. Desenvolvimento incremental

O projeto passou por diferentes versões até chegar ao protótipo atual.

A primeira etapa foi desenvolvida no Tinkercad e possuía uma lógica mais simples de seleção de destinos.

### 2.1 Primeira versão do sistema

Na primeira versão, a seleção da estação de destino era realizada por meio de **botões individuais**.

Essa versão ainda não possuía:

* teclado matricial;
* sistema de senha;
* deslocamento completo entre as diferentes estações;
* sistema de autenticação para retirada da carga.

O objetivo dessa etapa era validar inicialmente a lógica de movimentação e seleção de destino.

---

## 3. Desenvolvimento separado do sistema de senha

Paralelamente ao desenvolvimento da primeira versão, foi desenvolvido um módulo independente relacionado ao sistema de carga.

Esse módulo envolvia:

* teclado;
* display LCD;
* servo motor;
* abertura e fechamento do compartimento;
* geração e utilização de senha.

A decisão de desenvolver essa parte separadamente permitiu testar a lógica de controle da carga sem depender inicialmente de todo o sistema de navegação.

Posteriormente, esse módulo foi integrado ao restante do projeto.

---

## 4. Integração dos módulos

Após a validação dos módulos individuais, as funcionalidades foram integradas em um único projeto.

Entre as principais mudanças realizadas estão:

* substituição dos botões pelo teclado matricial;
* integração do teclado ao sistema principal;
* implementação da seleção de destino;
* implementação do sistema de senha;
* integração do servo motor;
* integração do LCD;
* implementação do deslocamento entre diferentes estações;
* integração da navegação com o sistema de carga.

A evolução pode ser representada da seguinte maneira:

```text
Versão inicial
     │
     ├── Botões para seleção
     ├── Navegação simplificada
     └── Sem autenticação
     │
     ▼
Módulo de carga
     │
     ├── Teclado
     ├── LCD
     ├── Servo
     └── Senha
     │
     ▼
Integração
     │
     ├── Teclado + navegação
     ├── Senha + carga
     ├── Seleção de destino
     └── Deslocamento entre estações
     │
     ▼
Protótipo atual
```

---

## 5. Evolução das estações

A lógica de navegação também evoluiu durante o desenvolvimento.

Nas primeiras versões, a representação das estações era mais limitada. A versão atual trabalha com as estações:

```text
A
B
C
D
```

O sistema permite selecionar uma estação de destino e realizar o deslocamento considerando a posição atual do robô.

Essa evolução foi importante para aproximar o protótipo da proposta original de um robô capaz de realizar entregas entre diferentes pontos do Centro de Tecnologia.

---

## 6. Estratégia de testes por módulos

Uma das principais estratégias adotadas durante o desenvolvimento foi realizar os testes de maneira modular.

Em vez de desenvolver todo o sistema e realizar apenas um teste ao final, os componentes foram implementados e testados individualmente antes da integração.

Entre os módulos desenvolvidos e testados estão:

* controle dos motores;
* sensores de seguimento de linha;
* detecção de estações;
* sensores ultrassônicos;
* LCD;
* teclado;
* servo motor;
* sistema de senha;
* comunicação I2C;
* seleção de destino;
* lógica de navegação;
* integração dos módulos.

Essa abordagem reduziu a possibilidade de um erro em um único módulo impedir a identificação do funcionamento dos demais.

---

## 7. Testes no Tinkercad

O circuito desenvolvido no Tinkercad foi testado diversas vezes durante o desenvolvimento.

Foram realizadas diferentes combinações de rotas e situações de operação para verificar o comportamento da lógica implementada.

De acordo com os testes realizados pela equipe, as funcionalidades presentes na versão final do circuito do Tinkercad foram validadas dentro do ambiente de simulação.

Os testes envolveram principalmente:

* seleção de diferentes destinos;
* deslocamento entre estações;
* funcionamento do sistema de senha;
* abertura e fechamento do compartimento;
* utilização do teclado;
* exibição de informações no LCD;
* detecção de obstáculos;
* funcionamento do seguimento de linha;
* comunicação entre os Arduinos.

---

## 8. Limitação dos sensores no Tinkercad

Uma dificuldade encontrada durante a implementação do seguidor de linha foi a disponibilidade de sensores no Tinkercad.

O ambiente não disponibiliza diretamente o sensor utilizado em muitas aplicações de robótica competitiva para seguimento de linha.

Para contornar essa limitação, foram utilizados sensores de luminosidade organizados em uma configuração em formato de cruz.

Essa solução foi utilizada como uma aproximação do funcionamento de um conjunto de sensores capaz de identificar a posição do robô em relação à linha.

Dessa forma, a solução utilizada no Tinkercad deve ser entendida como uma adaptação necessária às limitações do ambiente de simulação.

---

## 9. Decisão entre um ou dois Arduinos

Uma das principais discussões técnicas durante o desenvolvimento foi a definição da arquitetura eletrônica.

Foram consideradas duas possibilidades:

```text
Opção 1
Um Arduino
+
Expansores de I/O

Opção 2
Arduino principal
+
Arduino secundário
+
Comunicação I2C
```

Inicialmente, a equipe também tentou utilizar expansores de I/O.

Entretanto, foram encontradas limitações no ambiente do Tinkercad relacionadas à utilização de múltiplos expansores com diferentes endereços, principalmente quando um deles estava associado ao teclado.

Essa configuração apresentou dificuldades na leitura dos dispositivos.

---

## 10. Escolha da arquitetura com dois Arduinos

Após analisar as alternativas, a equipe optou pela utilização de dois Arduinos.

A arquitetura final utiliza:

```text
Arduino principal
      │
      │ I2C
      ▼
Arduino secundário
      │
      ▼
Teclado matricial
```

O Arduino principal permanece responsável pelo controle geral do robô, enquanto o Arduino secundário realiza a leitura do teclado e disponibiliza as teclas ao controlador principal.

---

## 11. Motivos para utilização de dois Arduinos

Além das limitações encontradas com os expansores no Tinkercad, a utilização de apenas um Arduino deixaria a utilização dos pinos bastante limitada.

A equipe identificou que uma arquitetura com apenas um Arduino exigiria alterações em outras partes do projeto.

Entre os problemas considerados estavam:

* limitação da quantidade de pinos disponíveis;
* necessidade de reorganizar o controle dos motores;
* necessidade de alterações na leitura dos sensores;
* possibilidade de utilização de pinos que também possuem funções importantes para comunicação serial;
* necessidade de substituir sensores por alternativas diferentes.

Um exemplo considerado pela equipe foi a necessidade de utilizar diferentes pinos de controle dos motores para manter determinadas funcionalidades de velocidade.

Também foi identificada a possibilidade de utilização de um sensor de três pinos em uma arquitetura alternativa, aumentando o custo e dificultando a obtenção do componente.

A arquitetura com dois Arduinos, portanto, permitiu distribuir melhor as funções do sistema.

---

## 12. Comunicação I2C

A comunicação I2C aumentou a complexidade do projeto, principalmente devido à necessidade de trabalhar com endereços diferentes para os dispositivos.

Entretanto, depois que a arquitetura de endereçamento foi definida, a comunicação pôde ser implementada e utilizada no sistema.

A arquitetura final utiliza o barramento I2C para comunicação entre:

* LCD;
* expansor PCF8574;
* Arduino secundário.

O Arduino secundário possui endereço próprio no barramento e fornece ao Arduino principal as teclas identificadas no teclado matricial.

---

## 13. Uso dos pinos de comunicação serial

Durante a análise da arquitetura com apenas um Arduino, também foi identificada a necessidade de utilizar pinos que possuem funções associadas à comunicação serial.

Essa solução poderia representar uma dificuldade adicional em uma futura implementação física, especialmente durante processos de programação, depuração e manutenção do robô.

Esse fator contribuiu para a decisão de distribuir as funções entre dois Arduinos.

---

## 14. Testes do sistema de senha

O sistema de senha foi desenvolvido inicialmente como um módulo separado e posteriormente integrado ao sistema principal.

Foram testados:

* geração da senha;
* exibição da senha no LCD;
* utilização do teclado;
* confirmação da carga;
* abertura do compartimento;
* solicitação da senha no destino;
* validação da senha;
* controle das tentativas;
* bloqueio após tentativas incorretas;
* abertura do compartimento após autenticação.

Essa integração permitiu conectar o sistema de navegação ao mecanismo de entrega da carga.

---

## 15. Testes de rota

Foram realizados testes com diferentes combinações de origem e destino no ambiente de simulação.

A lógica de navegação foi desenvolvida considerando as estações A, B, C e D e a orientação do robô.

O objetivo dos testes foi verificar se o sistema conseguia:

1. identificar a estação de origem;
2. receber a estação de destino;
3. determinar a orientação necessária;
4. executar a manobra inicial;
5. sair da estação de origem;
6. seguir a rota;
7. identificar a estação de destino;
8. solicitar a autenticação;
9. liberar o compartimento após a validação.

---

## 16. Testes no Webots

Além do Tinkercad, foram realizados testes de rota no Webots.

A simulação foi desenvolvida de forma a representar o conceito do projeto no ambiente do **Centro de Tecnologia da UFC**.

Nesse contexto, o Webots funciona como uma etapa intermediária entre a simulação abstrata dos componentes e a implementação física do robô.

A ideia pode ser representada como:

```text
Tinkercad
   │
   │ validação dos componentes
   ▼
Protótipo eletrônico
   │
   │
Webots + CT
   │
   │ representação do ambiente
   ▼
Protótipo físico futuro
```

A simulação no Webots permite representar o robô em uma escala de ambiente maior, aproximando a proposta do cenário em que o sistema seria utilizado.

---

## 17. Webots como representação do CT

Um dos objetivos da simulação no Webots foi levar a ideia das estações para o ambiente do Centro de Tecnologia.

Dessa forma, o ambiente simulado funciona como uma representação em maior escala do problema que o robô deverá resolver.

O processo pode ser entendido como:

```text
Estações do protótipo
        ↓
Rotas entre estações
        ↓
Representação do CT
        ↓
Simulação de deslocamento
        ↓
Futura aplicação física
```

Assim, o Webots não representa apenas um teste isolado do robô, mas uma tentativa de aproximar o protótipo do cenário real de utilização.

---

## 18. Desenvolvimento da modelagem mecânica

A modelagem mecânica foi desenvolvida separadamente das demais partes do projeto.

O objetivo inicial da equipe era construir efetivamente o robô e realizar sua operação no mundo real.

Entretanto, devido às limitações de tempo, recursos e logística da etapa de desenvolvimento, a construção de uma versão física móvel completa não pôde ser realizada.

---

## 19. Alternativa considerada para o protótipo físico

Após perceber as limitações para a construção do robô completo, foi considerada uma segunda alternativa.

A proposta seria utilizar:

* uma base de LEGO;
* controle remoto;
* chassi produzido em impressora 3D.

Essa alternativa permitiria demonstrar fisicamente a estrutura do robô sem exigir a construção de todo o sistema autônomo.

Posteriormente, entretanto, a equipe conseguiu desenvolver uma simulação no Webots que representava de forma mais adequada o comportamento esperado do robô.

Por isso, optou-se por utilizar a modelagem mecânica juntamente com a simulação virtual como principal forma de demonstração do protótipo.

---

## 20. Estado atual da modelagem

O chassi foi desenvolvido em OpenSCAD e representa a estrutura que seria utilizada em uma futura construção física.

A modelagem contempla elementos necessários ao sistema, incluindo:

* estrutura principal;
* compartimento de carga;
* alçapão;
* pontos de fixação;
* abertura para sensores ultrassônicos;
* suporte para os componentes;
* elementos relacionados ao LCD e teclado.

Dessa forma, mesmo sem a construção física completa, a modelagem fornece uma representação concreta de como o robô poderia ser construído.

---

## 21. O que não foi validado fisicamente

A principal limitação da etapa de desenvolvimento foi a ausência de uma integração física completa.

Não foi possível realizar, em hardware real, a integração de:

* chassi;
* motores;
* sensores;
* Arduinos;
* sistema de alimentação;
* servo;
* teclado;
* LCD;
* sistema de navegação;
* sistema de carga.

Portanto, não se deve interpretar os resultados das simulações como equivalentes a testes completos em um robô físico.

A validação realizada pela equipe foi predominantemente virtual, especialmente por meio do Tinkercad e do Webots.

---

## 22. Limitações e decisões de projeto

As principais limitações encontradas durante o desenvolvimento foram:

### Tinkercad

* disponibilidade limitada de determinados sensores;
* limitações na utilização de múltiplos expansores;
* dificuldades relacionadas a endereçamento de dispositivos;
* necessidade de adaptar o sistema de seguimento de linha.

### Arquitetura eletrônica

* quantidade limitada de pinos do Arduino;
* necessidade de distribuir as funções entre controladores;
* preocupação com utilização de pinos associados à comunicação serial.

### Webots

* curva de aprendizado elevada;
* complexidade para compreender inicialmente a estrutura do software;
* necessidade de dedicar uma parte significativa do desenvolvimento ao estudo da ferramenta.

### Implementação física

* tempo limitado;
* recursos disponíveis;
* logística para construção;
* impossibilidade de integrar e testar todos os componentes fisicamente durante a etapa.

---

## 23. Curva de aprendizado do Webots

O Webots apresentou uma curva de aprendizado significativa durante o desenvolvimento.

A ferramenta possui uma estrutura complexa e exigiu um período de estudo e experimentação para que a equipe pudesse compreender seu funcionamento.

Um dos integrantes ficou responsável por aprofundar o estudo da ferramenta e conseguiu desenvolver a simulação utilizada no projeto.

Esse processo permitiu que o Webots fosse incorporado ao projeto como uma ferramenta efetiva de prototipagem.

---

## 24. Resultado dos testes

Considerando o escopo efetivamente desenvolvido, os resultados podem ser divididos em dois grupos.

### Validação virtual

As funcionalidades implementadas no Tinkercad foram testadas pela equipe em diferentes situações e combinações de rota.

A simulação no Webots também foi utilizada para testar a representação das rotas e do ambiente do Centro de Tecnologia.

### Validação física

A integração completa em um robô físico não foi realizada durante esta etapa do projeto.

Essa etapa permanece como uma possibilidade de evolução futura.

---

## 25. Relação entre teste e desenvolvimento

Os testes não foram realizados somente ao final do projeto.

Eles fizeram parte do próprio processo de desenvolvimento.

A estratégia adotada foi:

```text
Implementar módulo
      ↓
Testar módulo
      ↓
Corrigir
      ↓
Testar novamente
      ↓
Integrar
      ↓
Testar sistema integrado
```

Esse processo foi aplicado principalmente ao desenvolvimento da eletrônica e do firmware.

A abordagem modular permitiu reduzir a quantidade de variáveis durante a identificação de problemas.

---

## 26. Estado final do protótipo

Ao final da etapa, o projeto apresenta três frentes principais integradas conceitualmente:

```text
┌─────────────────────────────┐
│        ROBÔ ENTREGADOR      │
├─────────────────────────────┤
│                             │
│  Eletrônica + Firmware      │
│  Tinkercad / Arduino        │
│                             │
├─────────────────────────────┤
│                             │
│  Modelagem mecânica         │
│  OpenSCAD                   │
│                             │
├─────────────────────────────┤
│                             │
│  Simulação                  │
│  Webots + ambiente do CT    │
│                             │
└─────────────────────────────┘
```

O resultado não deve ser entendido apenas como um circuito simulado ou como uma modelagem isolada.

O objetivo da etapa foi construir um **protótipo conceitual integrado**, no qual diferentes ferramentas representam diferentes aspectos de uma futura implementação física.

---

## 27. Próximas validações

Uma futura continuação do projeto poderia utilizar a estrutura desenvolvida nesta etapa para realizar a implementação física.

Entre as próximas etapas possíveis estão:

* fabricação do chassi;
* montagem dos componentes eletrônicos;
* instalação dos motores;
* integração dos sensores reais;
* alimentação independente;
* testes do seguidor de linha;
* testes de detecção de obstáculos;
* testes de navegação;
* integração do sistema de carga;
* testes de rota no ambiente físico;
* comparação entre os resultados da simulação e do protótipo real.

---

## 28. Conclusão

O processo de testes foi fundamental para a evolução do projeto.

O desenvolvimento incremental permitiu que os módulos fossem validados individualmente antes da integração, enquanto as simulações possibilitaram testar o comportamento do sistema sem a necessidade de construir imediatamente o robô completo.

As dificuldades encontradas também contribuíram para decisões importantes de arquitetura, como a utilização de dois Arduinos e a adaptação dos sensores disponíveis no Tinkercad.

Ao final, o projeto alcançou uma representação integrada do conceito do robô, combinando:

```text
Eletrônica
    +
Firmware
    +
Modelagem mecânica
    +
Navegação
    +
Simulação
```

A implementação física completa permanece como uma etapa futura, mas o protótipo desenvolvido fornece uma base para sua construção e evolução.

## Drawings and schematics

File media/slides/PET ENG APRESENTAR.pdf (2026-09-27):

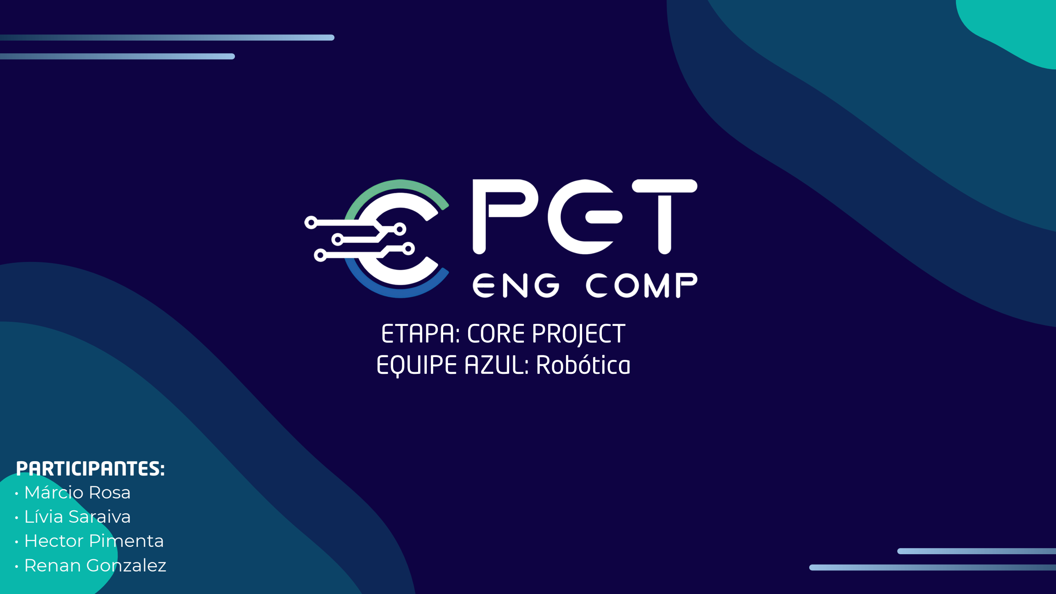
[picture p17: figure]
ETAPA: CORE PROJECT EQUIPE AZUL: Robótica; • Márcio Rosa • Lívia Saraiva • Hector Pimenta • Renan Gonzalez; PARTICIPANTES:
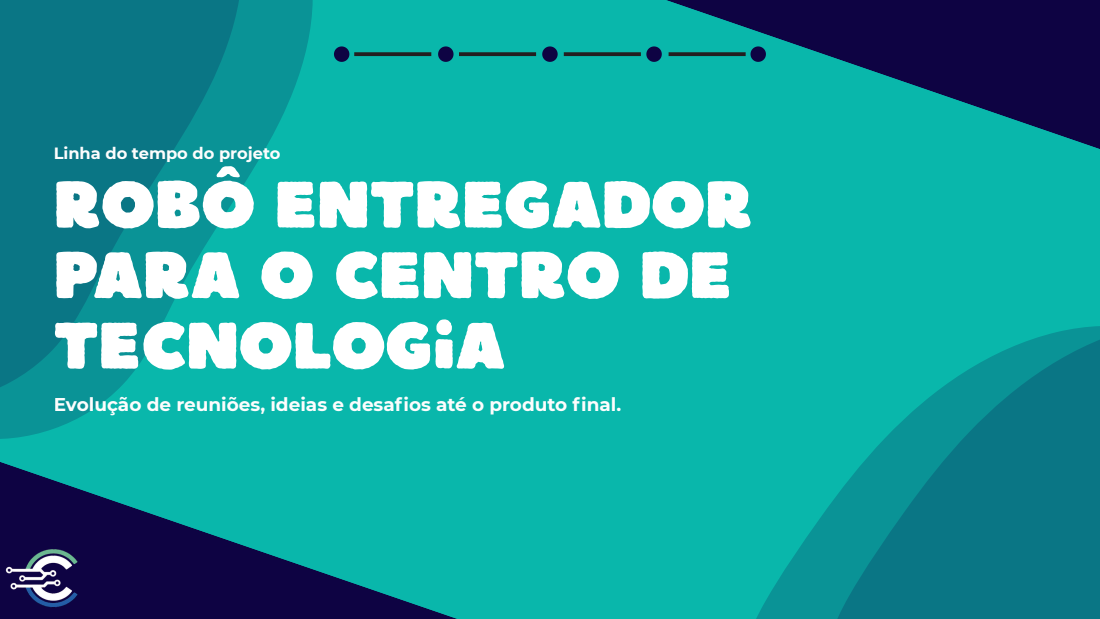
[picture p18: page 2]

Linha do tempo do projeto
Robô entregador
para o Centro de
Tecnologia

Evolução de reuniões, ideias e desafios até o produto final.

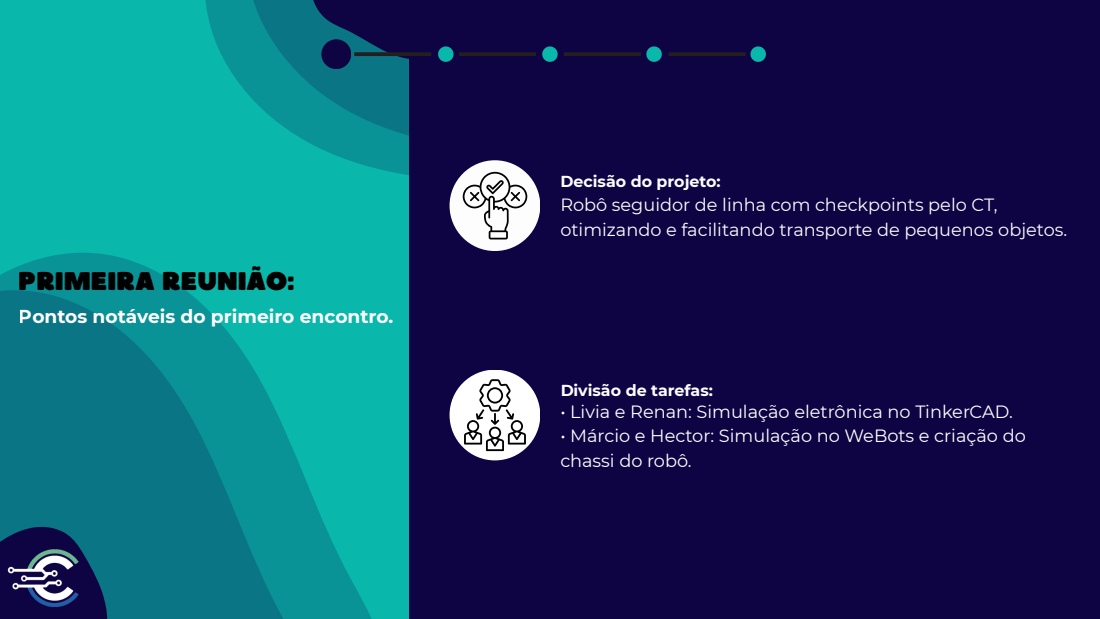
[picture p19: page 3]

Decisão do projeto:
Robô seguidor de linha com checkpoints pelo CT,
otimizando e facilitando transporte de pequenos objetos.

pRIMEIRA REUNIÃO:
Pontos notáveis do primeiro encontro.

Divisão de tarefas:
• Livia e Renan: Simulação eletrônica no TinkerCAD.
• Márcio e Hector: Simulação no WeBots e criação do
chassi do robô.

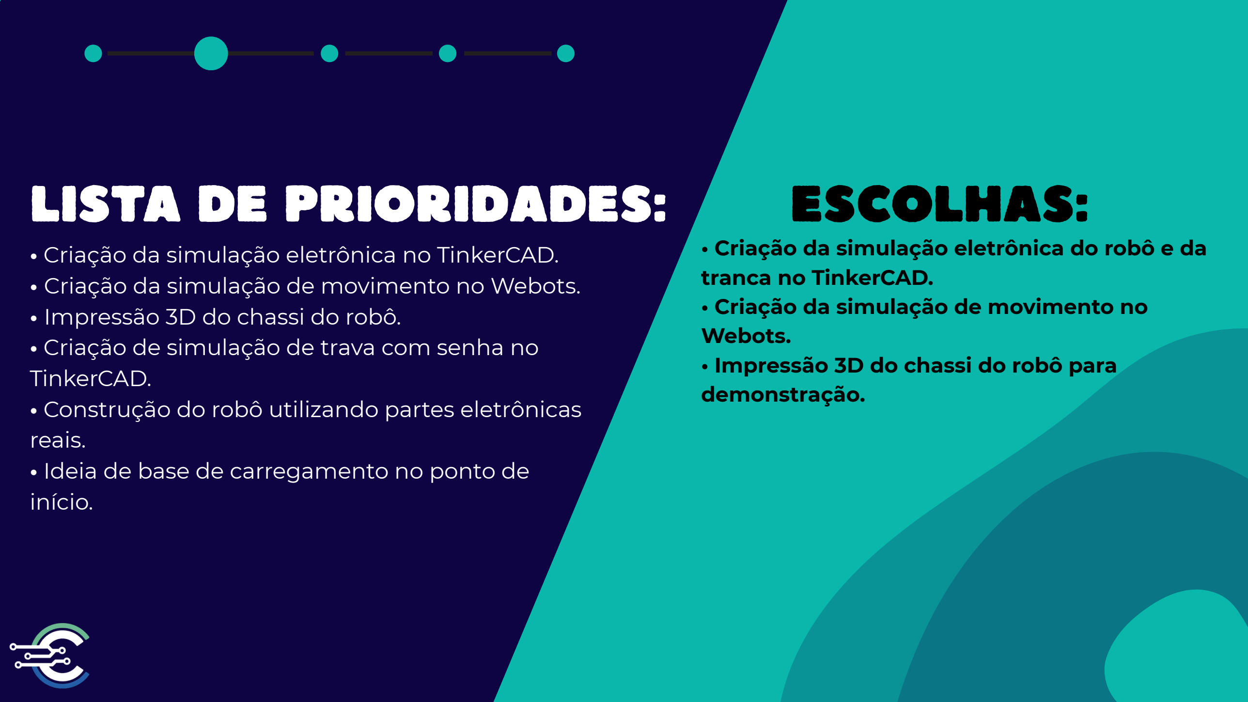
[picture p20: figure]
LISTA DE PRIORIDADES:; • Impressão 3D do chassi do robô.; TinkerCAD.; reais.; início.; escolhas:; tranca no TinkerCAD. • Criação da simulação de movimento no Webots. • Impressão 3D do chassi do robô para demonstração.

- Criação da simulação eletrônica no TinkerCAD.
- Criação da simulação de movimento no Webots.
- Criação de simulação de trava com senha no
- Construção do robô utilizando partes eletrônicas
- Ideia de base de carregamento no ponto de
- Criação da simulação eletrônica do robô e da

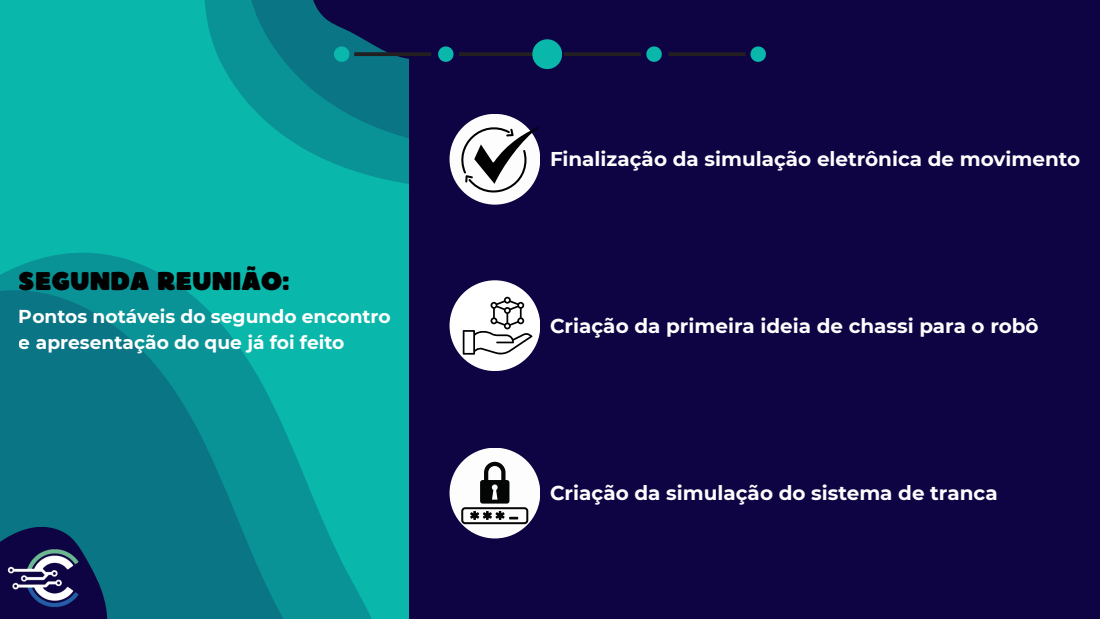
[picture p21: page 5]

Finalização da simulação eletrônica de movimento

Segunda REUNIÃO:
Pontos notáveis do segundo encontro
e apresentação do que já foi feito

Criação da primeira ideia de chassi para o robô

Criação da simulação do sistema de tranca

# componentes e estrutura do

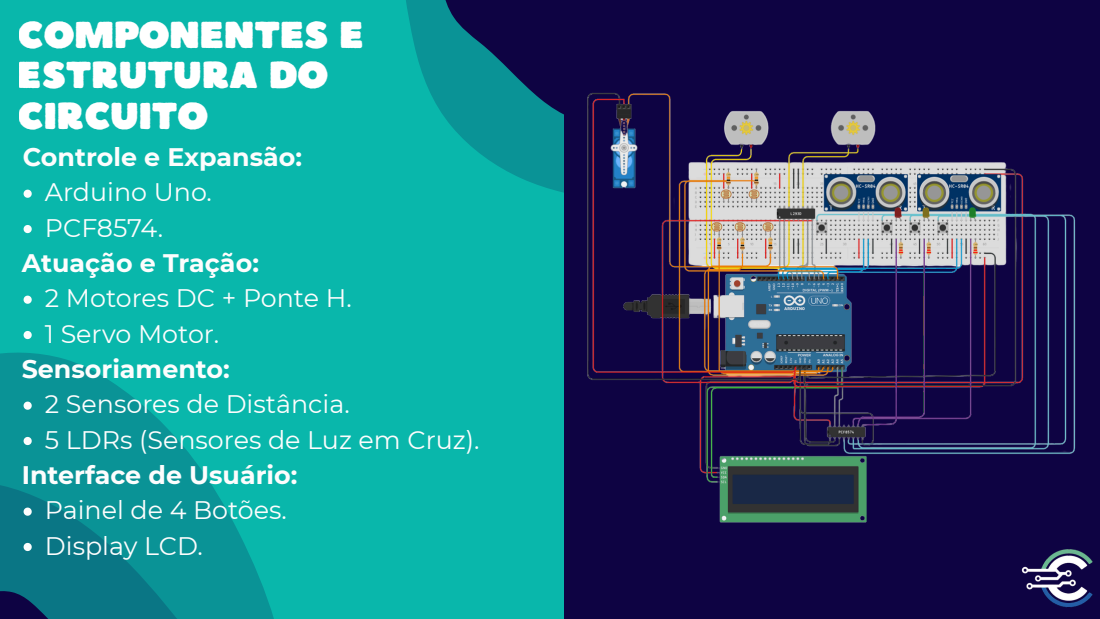
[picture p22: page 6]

cIRCUITO
Controle e Expansão:
Arduino Uno.
PCF8574.
Atuação e Tração:
2 Motores DC + Ponte H.
1 Servo Motor.
Sensoriamento:
2 Sensores de Distância.
5 LDRs (Sensores de Luz em Cruz).
Interface de Usuário:
Painel de 4 Botões.
Display LCD.

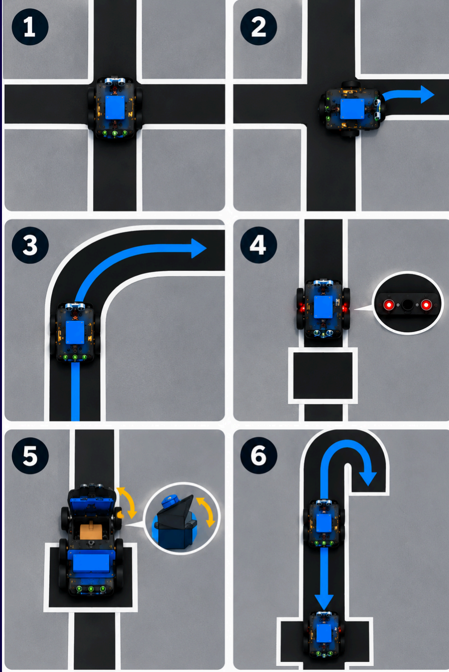
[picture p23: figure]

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
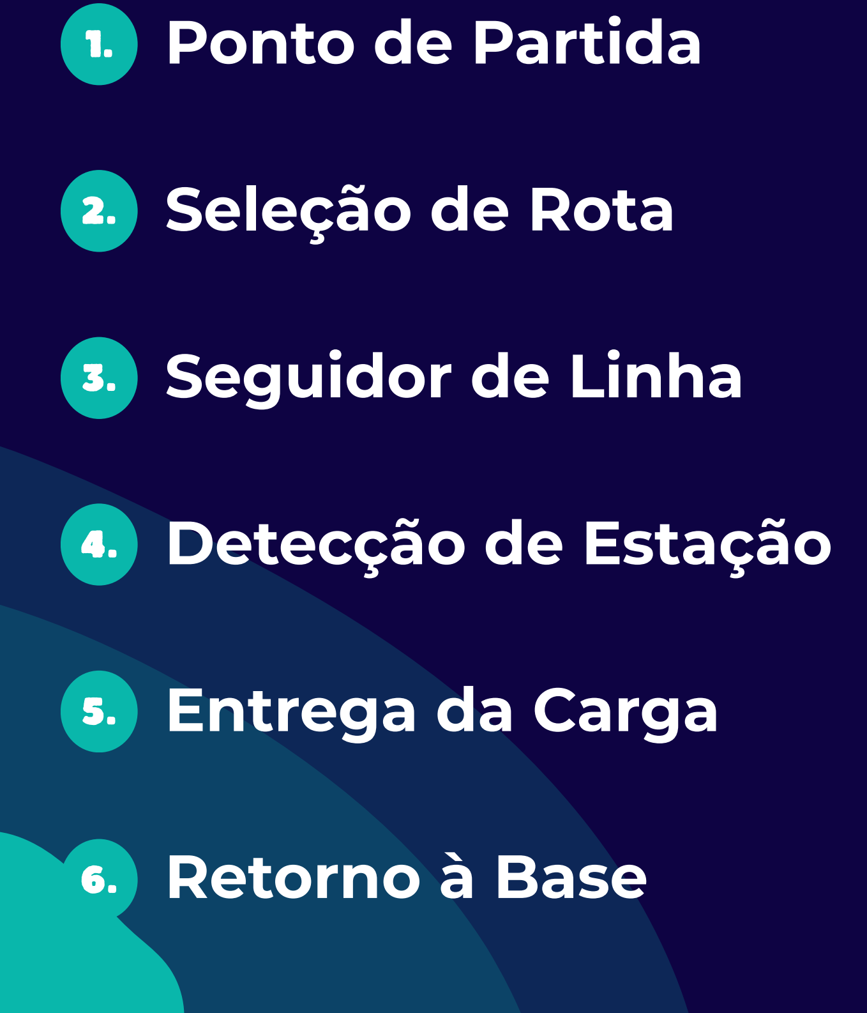
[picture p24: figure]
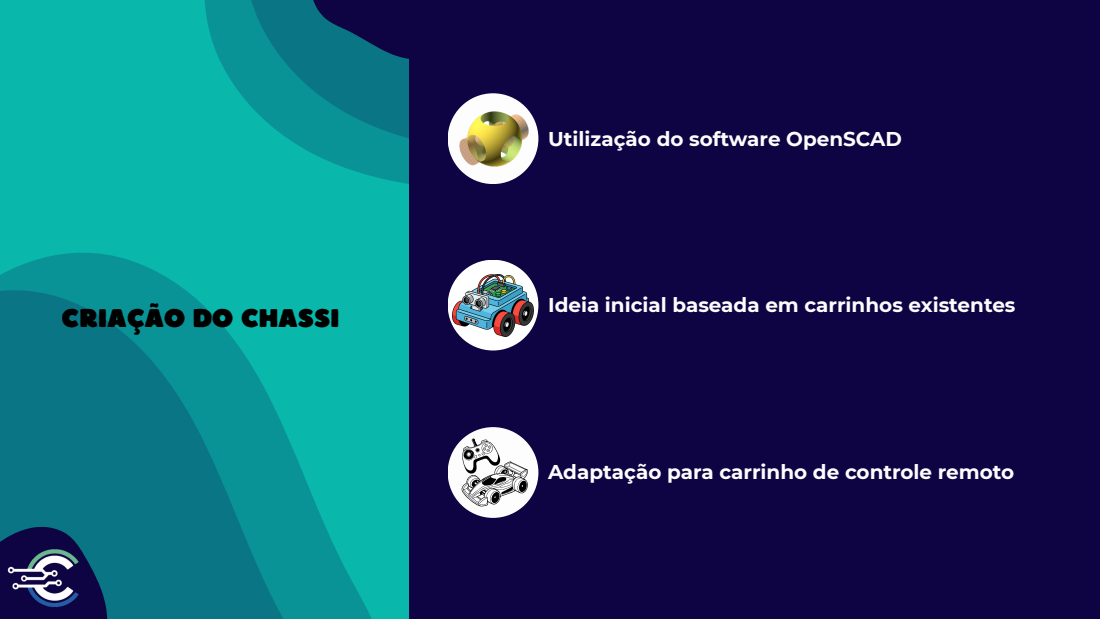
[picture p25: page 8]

Utilização do software OpenSCAD

Ideia inicial baseada em carrinhos existentes

crIAÇÃO DO CHASSI

Adaptação para carrinho de controle remoto

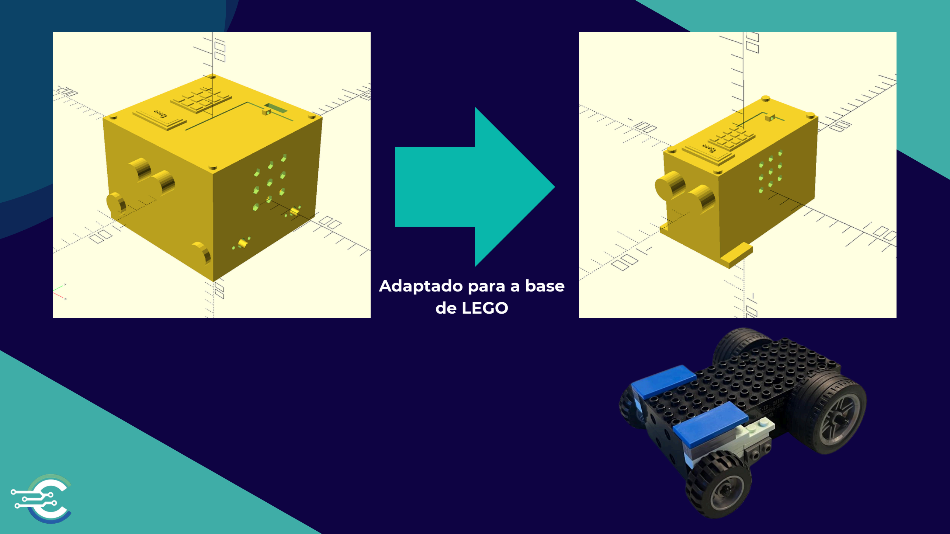
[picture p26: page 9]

Adaptado para a base
de LEGO

# sISTEMA DE TRANCA

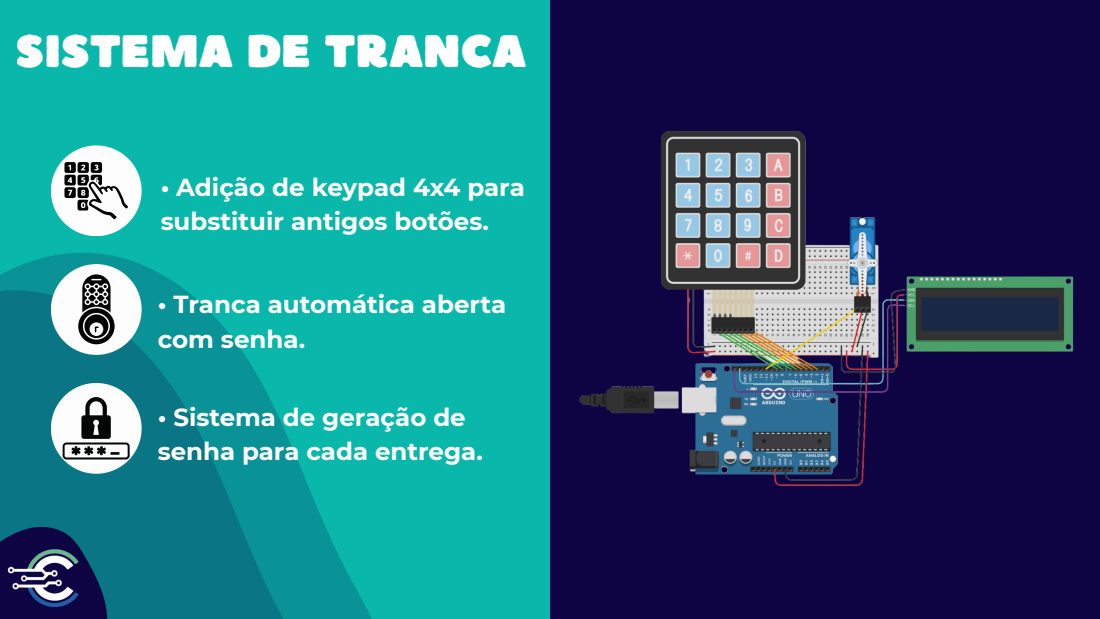
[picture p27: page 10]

• Adição de keypad 4x4 para
substituir antigos botões.

• Tranca automática aberta
com senha.

• Sistema de geração de
senha para cada entrega.

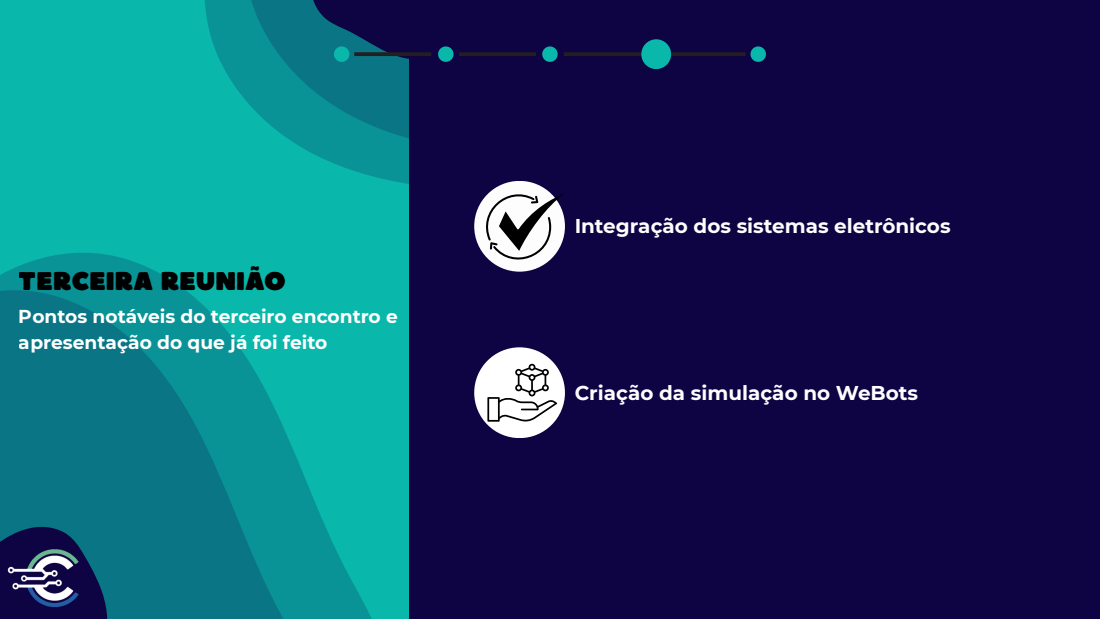
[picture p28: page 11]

Integração dos sistemas eletrônicos

tERCEIRA REUNIÃO
Pontos notáveis do terceiro encontro e
apresentação do que já foi feito

Criação da simulação no WeBots

# INTEGRAÇÃO DA ELETRÔNICA


• União das simulações de tranca e
de movimento

• Adição de segundo arduino para
ler as entradas do novo teclado


Utilização do software WeBots

crIAÇÃO NO WEBOTS

Locomoção do carrinho no mapa do CT

Simulação de movimento e funcionamento


# OBRIGADO PELA ATENÇÃO E PELA

# OPORTUNIDADE!

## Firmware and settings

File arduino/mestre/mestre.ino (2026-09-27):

#include <Wire.h>
#include <LiquidCrystal_I2C.h>
#include <Servo.h>

// ===== PINOS =====

// Motores
const byte MOTOR_ESQ_IN1 = 7;
const byte MOTOR_ESQ_IN2 = 8;
const byte MOTOR_ESQ_PWM = 5;

const byte MOTOR_DIR_IN1 = 9;
const byte MOTOR_DIR_IN2 = 10;
const byte MOTOR_DIR_PWM = 6;

// Seguidor de linha
const byte LDR_ESQ = A0;
const byte LDR_CEN = A1;
const byte LDR_DIR = A2;

// Estação
const byte LDR_EST_ESQ = A3;
const byte LDR_EST_DIR = 4;

// Ultrassônicos
const byte TRIG_ESQ = 11;
const byte ECHO_ESQ = 12;

const byte TRIG_DIR = 3;
const byte ECHO_DIR = 13;

// Servo
const byte PINO_SERVO = 2;

// I2C
const byte LCD_ENDERECO = 0x27;
const byte PCF_LED_ENDERECO = 0x20;
const byte TECLADO_ENDERECO = 0x10;

LiquidCrystal_I2C lcd(LCD_ENDERECO, 16, 2);
Servo servoPorta;


// ===== CONFIGURAÇÕES =====

const byte VELOCIDADE = 128;

const int LIMIAR_LDR = 300;
const int LIMIAR_LDR_ESTACAO = 100;

const int DISTANCIA_OBSTACULO = 30;

// Servo (ângulos reais, em graus)
const int ANGULO_SERVO_FECHADO = 0;
const int ANGULO_SERVO_ABERTO = 90;
const unsigned long TEMPO_MOVIMENTO_SERVO = 500;

// Manobras
const unsigned long TEMPO_CURVA = 700;
const unsigned long TEMPO_U = 1400;


// ===== DIREÇÕES =====

enum Direcao {
  NORTE,
  LESTE,
  SUL,
  OESTE
};

enum Manobra {
  RETO,
  DIREITA,
  ESQUERDA,
  U
};


// ===== ESTADOS =====

enum Estado {
  ESCOLHENDO_DESTINO,
  AGUARDANDO_CARGA,   
  MOSTRANDO_SENHA,
  DEVOLVENDO_CARGA,   
  MANOBRA_INICIAL,
  SAINDO_DA_ORIGEM,
  EM_VIAGEM,
  AGUARDANDO_SENHA,
  PORTA_ABERTA,
  SISTEMA_BLOQUEADO
};

Estado estadoAtual = ESCOLHENDO_DESTINO;


// ===== NAVEGAÇÃO =====

char estacaoAtual = 'A';
Direcao direcaoAtual = NORTE;
char origemViagem = 'A';
char destino = 'A';
bool destinoSelecionado = false;
Direcao direcaoDesejada = NORTE;
Manobra manobraAtual = RETO;


// ===== CONTROLE DA VIAGEM =====

unsigned long inicioManobra = 0;
bool saiuDaOrigem = false;

bool pausadoPorObstaculo = false;
unsigned long inicioPausa = 0;


// ===== SEGUIDOR =====

int ultimaDirecao = 0;


// ===== SENHA =====

char senhaViagem[5] = { '0', '0', '0', '0', '\0' };
char senhaDigitada[5] = { '\0', '\0', '\0', '\0', '\0' };
byte quantidadeSenha = 0;

// Controle de tentativas da senha da viagem
byte tentativasSenha = 0;
const byte MAX_TENTATIVAS_SENHA = 3;

// Código de manutenção para desbloqueio
char senhaManutencao[5] = { '1', '4', '0', '8', '\0' };
char codigoManutencao[5] = { '\0', '\0', '\0', '\0', '\0' };
byte quantidadeManutencao = 0;


// ===== CONTROLE DO TECLADO =====

unsigned long ultimaLeituraTeclado = 0;
const unsigned long INTERVALO_TECLADO = 50;


// ===== TELAS =====

void mostrarOrigemDestino() {
  lcd.clear();
  lcd.setCursor(0, 0);
  lcd.print("ORIGEM: ");
  lcd.print(estacaoAtual);
  lcd.setCursor(0, 1);
  lcd.print("DESTINO? (A-D)");
}

void mostrarDestinoEscolhido() {
  lcd.clear();
  lcd.setCursor(0, 0);
  lcd.print("DESTINO: ");
  lcd.print(destino);
  lcd.setCursor(0, 1);
  lcd.print("#=OK  *=VOLTA");
}

void mostrarAguardandoCarga() {
  lcd.clear();
  lcd.setCursor(0, 0);
  lcd.print("COLOQUE A CARGA");
  lcd.setCursor(0, 1);
  lcd.print("#=OK  *=CANCELA");
}

void mostrarDevolvendoCarga() {
  lcd.clear();
  lcd.setCursor(0, 0);
  lcd.print("RETIRE A CARGA");
  lcd.setCursor(0, 1);
  lcd.print("#=FECHAR");
}

void mostrarSenhaViagem() {
  lcd.clear();
  lcd.setCursor(0, 0);
  lcd.print("SENHA:");
  lcd.print(senhaViagem);
  lcd.setCursor(0, 1);
  lcd.print("#=INICIA *=VOLTA");
}

void mostrarViagem() {
  lcd.clear();
  lcd.setCursor(0, 0);
  lcd.print(origemViagem);
  lcd.print(" -> ");
  lcd.print(destino);
  lcd.setCursor(0, 1);
  lcd.print("EM VIAGEM");
}

void mostrarChegada() {
  lcd.clear();
  lcd.setCursor(0, 0);
  lcd.print("CHEGOU: ");
  lcd.print(destino);
  lcd.setCursor(0, 1);
  lcd.print("AGUARDE...");
}

void mostrarSenhaDestino() {
  lcd.clear();
  lcd.setCursor(0, 0);
  lcd.print("DIGITE A SENHA");
  lcd.setCursor(0, 1);
  for (byte i = 0; i < 4; i++) {
    lcd.print(i < quantidadeSenha ? '*' : '_');
  }
}

void mostrarSenhaCorreta() {
  lcd.clear();
  lcd.setCursor(0, 0);
  lcd.print("ACESSO LIBERADO");
  lcd.setCursor(0, 1);
  lcd.print("RETIRE A CARGA");
}

void mostrarSenhaErrada(byte tentativasRestantes) {
  lcd.clear();
  lcd.setCursor(0, 0);
  lcd.print("SENHA INCORRETA");
  lcd.setCursor(0, 1);

  if (tentativasRestantes > 0) {
    lcd.print("RESTAM ");
    lcd.print(tentativasRestantes);
    lcd.print(" TENT.");
  }
  else {
    lcd.print("TENTE NOVAMENTE");
  }

  delay(1200);

  mostrarSenhaDestino();
}

void mostrarSistemaBloqueado() {
  lcd.clear();
  lcd.setCursor(0, 0);
  lcd.print("SISTEMA BLOQ.");
  lcd.setCursor(0, 1);
  lcd.print("COD. MANUTENCAO");
}

void mostrarCodigoManutencao() {
  lcd.clear();
  lcd.setCursor(0, 0);
  lcd.print("COD. MANUTENCAO");
  lcd.setCursor(0, 1);

  for (byte i = 0; i < quantidadeManutencao; i++) {
    lcd.print('*');
  }
}


// ===== MOTORES =====

void motoresFrente(byte velocidade) {
  digitalWrite(MOTOR_ESQ_IN1, HIGH);
  digitalWrite(MOTOR_ESQ_IN2, LOW);

  digitalWrite(MOTOR_DIR_IN1, HIGH);
  digitalWrite(MOTOR_DIR_IN2, LOW);

  analogWrite(MOTOR_ESQ_PWM, velocidade);
  analogWrite(MOTOR_DIR_PWM, velocidade);
}

void virarDireita(byte velocidade) {
  digitalWrite(MOTOR_ESQ_IN1, HIGH);
  digitalWrite(MOTOR_ESQ_IN2, LOW);

  digitalWrite(MOTOR_DIR_IN1, LOW);
  digitalWrite(MOTOR_DIR_IN2, HIGH);

  analogWrite(MOTOR_ESQ_PWM, velocidade);
  analogWrite(MOTOR_DIR_PWM, velocidade);
}

void virarEsquerda(byte velocidade) {
  digitalWrite(MOTOR_ESQ_IN1, LOW);
  digitalWrite(MOTOR_ESQ_IN2, HIGH);

  digitalWrite(MOTOR_DIR_IN1, HIGH);
  digitalWrite(MOTOR_DIR_IN2, LOW);

  analogWrite(MOTOR_ESQ_PWM, velocidade);
  analogWrite(MOTOR_DIR_PWM, velocidade);
}

void manobraU(byte velocidade) {
  virarEsquerda(velocidade);
}

void pararMotores() {
  analogWrite(MOTOR_ESQ_PWM, 0);
  analogWrite(MOTOR_DIR_PWM, 0);
}


// ===== SEGUIDOR DE LINHA =====

void followTrack() {
  int esquerda = analogRead(LDR_ESQ);
  int centro = analogRead(LDR_CEN);
  int direita = analogRead(LDR_DIR);

  bool pistaEsquerda = esquerda < LIMIAR_LDR;
  bool pistaCentro = centro < LIMIAR_LDR;
  bool pistaDireita = direita < LIMIAR_LDR;

  if (pistaEsquerda && !pistaCentro && !pistaDireita) {
    virarEsquerda(VELOCIDADE);
    ultimaDirecao = -1;
  }
  else if (pistaEsquerda && pistaCentro && !pistaDireita) {
    virarEsquerda(VELOCIDADE);
    ultimaDirecao = -1;
  }
  else if (!pistaEsquerda && pistaCentro && !pistaDireita) {
    motoresFrente(VELOCIDADE);
    ultimaDirecao = 0;
  }
  else if (!pistaEsquerda && pistaCentro && pistaDireita) {
    virarDireita(VELOCIDADE);
    ultimaDirecao = 1;
  }
  else if (!pistaEsquerda && !pistaCentro && pistaDireita) {
    virarDireita(VELOCIDADE);
    ultimaDirecao = 1;
  }
  else if (!pistaEsquerda && !pistaCentro && !pistaDireita) {
    if (ultimaDirecao == -1) {
      virarEsquerda(VELOCIDADE);
    }
    else if (ultimaDirecao == 1) {
      virarDireita(VELOCIDADE);
    }
    else {
      pararMotores();
    }
  }
  else {
    motoresFrente(VELOCIDADE);
    ultimaDirecao = 0;
  }
}


// ===== DETECÇÃO DE ESTAÇÃO =====

bool estacaoDetectada() {
  int esquerda = analogRead(LDR_EST_ESQ);
  int direita = digitalRead(LDR_EST_DIR);

  bool estacaoEsquerda = esquerda < LIMIAR_LDR_ESTACAO;
  bool estacaoDireita = direita == LOW;

  return estacaoEsquerda && estacaoDireita;
}


// ===== ULTRASSÔNICOS =====

long medirDistancia(byte trig, byte echo) {
  digitalWrite(trig, LOW);
  delayMicroseconds(2);

  digitalWrite(trig, HIGH);
  delayMicroseconds(10);

  digitalWrite(trig, LOW);

  unsigned long duracao = pulseIn(echo, HIGH, 30000);

  if (duracao == 0) {
    return DISTANCIA_OBSTACULO + 1;
  }

  return duracao / 58;
}

unsigned long ultimaChecagemObstaculo = 0;
const unsigned long INTERVALO_OBSTACULO = 100;
bool obstaculoFoiDetectado = false;

bool obstaculoDetectado() {
  if (millis() - ultimaChecagemObstaculo < INTERVALO_OBSTACULO) {
    return obstaculoFoiDetectado;
  }

  ultimaChecagemObstaculo = millis();

  long esquerda = medirDistancia(TRIG_ESQ, ECHO_ESQ);

  if (esquerda < DISTANCIA_OBSTACULO) {
    obstaculoFoiDetectado = true;
    return true;
  }

  long direita = medirDistancia(TRIG_DIR, ECHO_DIR);

  obstaculoFoiDetectado = (direita < DISTANCIA_OBSTACULO);
  return obstaculoFoiDetectado;
}


// ===== SERVO =====

void servoAbrir() {
  lcd.clear();
  lcd.setCursor(0, 0);
  lcd.print("ABRINDO...");

  servoPorta.attach(PINO_SERVO);
  servoPorta.write(ANGULO_SERVO_ABERTO);
  delay(TEMPO_MOVIMENTO_SERVO);
  servoPorta.detach();
}

void servoFechar() {
  lcd.clear();
  lcd.setCursor(0, 0);
  lcd.print("FECHANDO...");

  servoPorta.attach(PINO_SERVO);
  servoPorta.write(ANGULO_SERVO_FECHADO);
  delay(TEMPO_MOVIMENTO_SERVO);
  servoPorta.detach();
}


// ===== LEDS (PCF8574) =====

void pcf8574Enviar(byte valor) {
  Wire.beginTransmission(PCF_LED_ENDERECO);
  Wire.write(valor);
  Wire.endTransmission();
}

void desligarTodosLeds() {
  pcf8574Enviar(0xFF);
}

void ledDestino(char destinoEscolhido) {
  byte valor = 0xFF;

  if (destinoEscolhido == 'A') {
    valor &= ~(1 << 7); // branco 
  }
  else if (destinoEscolhido == 'B') {
    valor &= ~(1 << 4); // vermelho
  }
  else if (destinoEscolhido == 'C') {
    valor &= ~(1 << 5); // amarelo
  }
  else if (destinoEscolhido == 'D') {
    valor &= ~(1 << 6); // verde
  }

  pcf8574Enviar(valor);
}


// ===== NAVEGAÇÃO =====

byte obterDirecaoDestino(char origem, char destinoEscolhido) {
  if (origem == 'A') {
    if (destinoEscolhido == 'B') return LESTE;
    if (destinoEscolhido == 'C') return NORTE;
    if (destinoEscolhido == 'D') return OESTE;
  }

  if (origem == 'B') {
    if (destinoEscolhido == 'A') return SUL;
    if (destinoEscolhido == 'C') return NORTE;
    if (destinoEscolhido == 'D') return LESTE;
  }

  if (origem == 'C') {
    if (destinoEscolhido == 'A') return SUL;
    if (destinoEscolhido == 'B') return LESTE;
    if (destinoEscolhido == 'D') return OESTE;
  }

  if (origem == 'D') {
    if (destinoEscolhido == 'A') return LESTE;
    if (destinoEscolhido == 'B') return OESTE;
    if (destinoEscolhido == 'C') return NORTE;
  }

  return direcaoAtual;
}

byte obterOrientacaoChegada(char origem, char destinoEscolhido) {
  if (origem == 'A' && destinoEscolhido == 'B') return NORTE;
  if (origem == 'A' && destinoEscolhido == 'C') return NORTE;
  if (origem == 'A' && destinoEscolhido == 'D') return OESTE;

  if (origem == 'B' && destinoEscolhido == 'A') return OESTE;
  if (origem == 'B' && destinoEscolhido == 'C') return OESTE;
  if (origem == 'B' && destinoEscolhido == 'D') return LESTE;

  if (origem == 'C' && destinoEscolhido == 'A') return SUL;
  if (origem == 'C' && destinoEscolhido == 'B') return SUL;
  if (origem == 'C' && destinoEscolhido == 'D') return SUL;

  if (origem == 'D' && destinoEscolhido == 'A') return LESTE;
  if (origem == 'D' && destinoEscolhido == 'B') return OESTE;
  if (origem == 'D' && destinoEscolhido == 'C') return LESTE;

  return direcaoAtual;
}

byte calcularManobra(byte atual, byte desejada) {
  if (atual == desejada) {
    return RETO;
  }

  if (
    (atual == NORTE && desejada == LESTE) ||
    (atual == LESTE && desejada == SUL) ||
    (atual == SUL && desejada == OESTE) ||
    (atual == OESTE && desejada == NORTE)
  ) {
    return DIREITA;
  }

  if (
    (atual == NORTE && desejada == OESTE) ||
    (atual == OESTE && desejada == SUL) ||
    (atual == SUL && desejada == LESTE) ||
    (atual == LESTE && desejada == NORTE)
  ) {
    return ESQUERDA;
  }

  return U;
}


// ===== TECLADO =====

char lerTecla() {
  if (millis() - ultimaLeituraTeclado < INTERVALO_TECLADO) {
    return 0;
  }

  ultimaLeituraTeclado = millis();

  Wire.requestFrom(TECLADO_ENDERECO, (byte)1);

  if (Wire.available()) {
    char tecla = Wire.read();

    if (tecla != 0) {
      return tecla;
    }
  }

  return 0;
}


// ===== SENHA =====

void gerarSenha() {
  for (byte i = 0; i < 4; i++) {
    senhaViagem[i] = '0' + random(0, 10);
  }

  senhaViagem[4] = '\0';
}

void limparSenhaDigitada() {
  quantidadeSenha = 0;

  for (byte i = 0; i < 5; i++) {
    senhaDigitada[i] = '\0';
  }
}

bool senhaEstaCorreta() {
  if (quantidadeSenha != 4) {
    return false;
  }

  for (byte i = 0; i < 4; i++) {
    if (senhaDigitada[i] != senhaViagem[i]) {
      return false;
    }
  }

  return true;
}


// ===== CÓDIGO DE MANUTENÇÃO =====

void limparCodigoManutencao() {
  quantidadeManutencao = 0;

  for (byte i = 0; i < 5; i++) {
    codigoManutencao[i] = '\0';
  }
}

bool codigoManutencaoCorreto() {
  if (quantidadeManutencao != 4) {
    return false;
  }

  for (byte i = 0; i < 4; i++) {
    if (codigoManutencao[i] != senhaManutencao[i]) {
      return false;
    }
  }

  return true;
}


// ===== PREPARAR VIAGEM =====

void prepararViagem() {
  origemViagem = estacaoAtual;

  direcaoDesejada = (Direcao)obterDirecaoDestino(origemViagem, destino);
  manobraAtual = (Manobra)calcularManobra(direcaoAtual, direcaoDesejada);

  saiuDaOrigem = false;
  pausadoPorObstaculo = false;

  ledDestino(destino);
  mostrarViagem();

  inicioManobra = millis();

  if (manobraAtual == RETO) {
    estadoAtual = SAINDO_DA_ORIGEM;
  }
  else {
    estadoAtual = MANOBRA_INICIAL;
  }
}


// ===== MANOBRA INICIAL =====

void executarManobraInicial() {
  if (obstaculoDetectado()) {
    pararMotores();

    if (!pausadoPorObstaculo) {
      pausadoPorObstaculo = true;
      inicioPausa = millis();
    }

    tratarObstaculoNaViagem();
    return;
  }
  
  if (pausadoPorObstaculo) {
    inicioManobra += (millis() - inicioPausa);
    pausadoPorObstaculo = false;
  }

  limparAvisoObstaculo();

  unsigned long tempo = millis() - inicioManobra;

  if (manobraAtual == DIREITA) {
    virarDireita(VELOCIDADE);

    if (tempo >= TEMPO_CURVA) {
      pararMotores();
      estadoAtual = SAINDO_DA_ORIGEM;
    }
  }
  else if (manobraAtual == ESQUERDA) {
    virarEsquerda(VELOCIDADE);

    if (tempo >= TEMPO_CURVA) {
      pararMotores();
      estadoAtual = SAINDO_DA_ORIGEM;
    }
  }
  else if (manobraAtual == U) {
    manobraU(VELOCIDADE);

    if (tempo >= TEMPO_U) {
      pararMotores();
      estadoAtual = SAINDO_DA_ORIGEM;
    }
  }
  else {
    estadoAtual = SAINDO_DA_ORIGEM;
  }
}


// ===== AVISO DE OBSTÁCULO PERSISTENTE =====
// Puramente visual: se o robô ficar parado por obstáculo por tempo
// demais, avisa no LCD. Não interfere em nenhum timer de manobra nem
// na lógica de obstaculoDetectado()/movimento.

bool avisoObstaculoAtivo = false;
bool avisoObstaculoExibido = false;
unsigned long inicioObstaculoViagem = 0;
const unsigned long TEMPO_AVISO_OBSTACULO = 2000;

void tratarObstaculoNaViagem() {
  if (!avisoObstaculoAtivo) {
    avisoObstaculoAtivo = true;
    avisoObstaculoExibido = false;
    inicioObstaculoViagem = millis();
    return;
  }

  if (!avisoObstaculoExibido && millis() - inicioObstaculoViagem >= TEMPO_AVISO_OBSTACULO) {
    lcd.setCursor(0, 1);
    lcd.print("OBSTACULO NA VIA");
    avisoObstaculoExibido = true;
  }
}

void limparAvisoObstaculo() {
  if (avisoObstaculoAtivo) {
    avisoObstaculoAtivo = false;

    if (avisoObstaculoExibido) {
      mostrarViagem();
    }
  }
}


// ===== SAIR DA ORIGEM =====

void sairDaOrigem() {
  if (obstaculoDetectado()) {
    pararMotores();
    tratarObstaculoNaViagem();
    return;
  }

  limparAvisoObstaculo();
  followTrack();

  // Enquanto estiver sobre a marca da origem, não pode considerar
  // que já chegou ao destino.
  if (!estacaoDetectada()) {
    saiuDaOrigem = true;
    estadoAtual = EM_VIAGEM;
    mostrarViagem();
  }
}


// ===== VIAGEM =====

void executarViagem() {
  if (obstaculoDetectado()) {
    pararMotores();
    tratarObstaculoNaViagem();
    return;
  }

  limparAvisoObstaculo();
  followTrack();

  // Só procura estação depois de ter saído da origem.
  if (saiuDaOrigem && estacaoDetectada()) {
    pararMotores();

    estacaoAtual = destino;
    direcaoAtual = (Direcao)obterOrientacaoChegada(origemViagem, destino);

    desligarTodosLeds();
    limparSenhaDigitada();

    // Começa uma nova contagem de tentativas ao chegar ao destino.
    tentativasSenha = 0;

    mostrarChegada();
    delay(500);

    estadoAtual = AGUARDANDO_SENHA;
    mostrarSenhaDestino();
  }
}


// ===== ESCOLHA DO DESTINO =====

void processarEscolhaDestino(char tecla) {
  if (tecla == 0) {
    return;
  }

  if (tecla == '*') {
    destinoSelecionado = false;
    mostrarOrigemDestino();
    return;
  }

  if (tecla >= 'A' && tecla <= 'D') {
    char novoDestino = tecla;

    if (novoDestino == estacaoAtual) {
      lcd.clear();
      lcd.setCursor(0, 0);
      lcd.print("DESTINO INVALIDO");
      lcd.setCursor(0, 1);
      lcd.print("ESCOLHA OUTRO");

      delay(1000);

      mostrarOrigemDestino();
      return;
    }

    destino = novoDestino;
    destinoSelecionado = true;
    mostrarDestinoEscolhido();
    return;
  }

  if (tecla == '#' && destinoSelecionado) {
    // Abre o compartimento para o usuário colocar a carga antes de
    // gerar a senha e iniciar a viagem.
    servoAbrir();

    estadoAtual = AGUARDANDO_CARGA;
    mostrarAguardandoCarga();
  }
}


// ===== AGUARDANDO CARGA (recebimento do item na origem) =====

void processarAguardandoCarga(char tecla) {
  if (tecla == 0) {
    return;
  }

  if (tecla == '#') {
    // Carga colocada: fecha o compartimento e só então gera a senha
    // que vai liberar o item no destino.
    servoFechar();

    gerarSenha();
    mostrarSenhaViagem();

    estadoAtual = MOSTRANDO_SENHA;
    return;
  }

  if (tecla == '*') {
    // Cancelou antes de confirmar a carga: fecha o compartimento
    // (ainda vazio) e volta para a escolha de destino.
    servoFechar();

    destinoSelecionado = false;
    mostrarOrigemDestino();

    estadoAtual = ESCOLHENDO_DESTINO;
  }
}


// ===== APÓS MOSTRAR A SENHA (espera # para começar) =====

void processarSenhaMostrada(char tecla) {
  if (tecla == 0) {
    return;
  }

  if (tecla == '#') {
    prepararViagem();
    return;
  }

  if (tecla == '*') {
    // A carga já está dentro do compartimento nesta etapa: reabre a
    // porta para o usuário poder retirá-la antes de cancelar de vez.
    servoAbrir();
    mostrarDevolvendoCarga();

    estadoAtual = DEVOLVENDO_CARGA;
  }
}


// ===== DEVOLVENDO CARGA (viagem cancelada após colocar o item) =====

void processarDevolvendoCarga(char tecla) {
  if (tecla == 0) {
    return;
  }

  if (tecla == '#' || tecla == '*') {
    servoFechar();

    destinoSelecionado = false;
    mostrarOrigemDestino();

    estadoAtual = ESCOLHENDO_DESTINO;
  }
}


// ===== SENHA NA ESTAÇÃO DE DESTINO =====

void processarSenhaDestino(char tecla) {
  if (tecla == 0) {
    return;
  }

  if (tecla == '*') {
    limparSenhaDigitada();
    mostrarSenhaDestino();
    return;
  }

  if (tecla >= '0' && tecla <= '9') {
    if (quantidadeSenha < 4) {
      senhaDigitada[quantidadeSenha] = tecla;
      quantidadeSenha++;
      mostrarSenhaDestino();
    }
    return;
  }

  if (tecla == '#') {
    if (senhaEstaCorreta()) {
      servoAbrir();
      mostrarSenhaCorreta();

      // Senha correta: zera as tentativas.
      tentativasSenha = 0;

      estadoAtual = PORTA_ABERTA;
    }
    else {
      tentativasSenha++;

      if (tentativasSenha >= MAX_TENTATIVAS_SENHA) {
        limparSenhaDigitada();
        limparCodigoManutencao();

        estadoAtual = SISTEMA_BLOQUEADO;

        mostrarSistemaBloqueado();

        delay(1500);

        mostrarCodigoManutencao();
      }
      else {
        mostrarSenhaErrada(MAX_TENTATIVAS_SENHA - tentativasSenha);
        limparSenhaDigitada();
      }
    }
  }
}


// ===== SISTEMA BLOQUEADO =====
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
void loop() {
  char tecla = 0;

  // O teclado só é acessado nos estados em que ele é realmente
  // necessário; durante manobra e viagem não há requisição I2C.
  if (
    estadoAtual == ESCOLHENDO_DESTINO ||
    estadoAtual == AGUARDANDO_CARGA ||
    estadoAtual == MOSTRANDO_SENHA ||
    estadoAtual == DEVOLVENDO_CARGA ||
    estadoAtual == AGUARDANDO_SENHA ||
    estadoAtual == PORTA_ABERTA ||
    estadoAtual == SISTEMA_BLOQUEADO
  ) {
    tecla = lerTecla();
  }

  switch (estadoAtual) {
    case ESCOLHENDO_DESTINO:
      processarEscolhaDestino(tecla);
      break;

    case AGUARDANDO_CARGA:
      processarAguardandoCarga(tecla);
      break;

    case MOSTRANDO_SENHA:
      processarSenhaMostrada(tecla);
      break;

    case DEVOLVENDO_CARGA:
      processarDevolvendoCarga(tecla);
      break;

    case MANOBRA_INICIAL:
      executarManobraInicial();
      break;

    case SAINDO_DA_ORIGEM:
      sairDaOrigem();
      break;

    case EM_VIAGEM:
      executarViagem();
      break;

    case AGUARDANDO_SENHA:
      processarSenhaDestino(tecla);
      break;

    case PORTA_ABERTA:
      processarPortaAberta(tecla);
      break;

    case SISTEMA_BLOQUEADO:
      processarSistemaBloqueado(tecla);
      break;
  }
}

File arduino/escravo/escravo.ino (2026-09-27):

#include <Wire.h>

const byte linhas[4] = {2, 3, 4, 5};
const byte colunas[4] = {6, 7, 8, 9};

char teclas[4][4] = {
  {'1', '2', '3', 'A'},
  {'4', '5', '6', 'B'},
  {'7', '8', '9', 'C'},
  {'*', '0', '#', 'D'}
};

volatile char teclaParaEnviar = 0;

void enviarTecla() {
  Wire.write(teclaParaEnviar);
  teclaParaEnviar = 0;
}

void setup() {
  Wire.begin(0x10);
  Wire.onRequest(enviarTecla);

  for (byte i = 0; i < 4; i++) {
    pinMode(linhas[i], OUTPUT);
    digitalWrite(linhas[i], HIGH);
  }

  for (byte i = 0; i < 4; i++) {
    pinMode(colunas[i], INPUT_PULLUP);
  }
}

void loop() {

  for (byte linha = 0; linha < 4; linha++) {

    for (byte i = 0; i < 4; i++) {
      digitalWrite(linhas[i], HIGH);
    }

    digitalWrite(linhas[linha], LOW);

    for (byte coluna = 0; coluna < 4; coluna++) {

      if (digitalRead(colunas[coluna]) == LOW) {

        teclaParaEnviar = teclas[linha][coluna];

        while (digitalRead(colunas[coluna]) == LOW) {
          delay(10);
        }

        delay(50);
      }
    }
  }
}

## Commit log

2026-09-27 Cria chassi.scad
    [chassi.scad]
2026-09-27 Adiciona código do chassi
    [chassi.scad]
2026-09-27 Adiciona projeto de simulacao Webots
2026-09-27 Adiciona documentação de eletrônica e firmware
    Documentação detalhada sobre o robô entregador, incluindo visão geral, arquitetura eletrônica, componentes principais, pinagem do Arduino, controle de motores, detecção de obstáculos, sistema de nave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
2026-09-27 Documenta o projeto mecânico
    Foi adicionada documentação detalhada sobre a estrutura mecânica e a modelagem 3D do robô de entrega, incluindo dimensões, componentes e integração com a eletrônica.
2026-09-27 Documenta controle e navegação do robô
    Adicionada documentação detalhada para o software ROBÔ ENTREGADOR, abrangendo visão geral, organização, máquina de estados e fluxo operacional.
2026-09-27 Documenta simulação no Webots
    Documente a simulação do robô de entrega utilizando o Webots, detalhando sua organização, objetivos e componentes.
2026-09-27 Documenta testes e evolução do projeto
    Documente o processo de desenvolvimento e testes incrementais do projeto de robô de entrega, detalhando a integração de módulos, as estratégias de teste e as futuras etapas de validação.
2026-09-27 Cria pasta para apresentação
2026-09-27 Cria pasta para vídeos
2026-09-27 Cria pasta para o manual
2026-09-27 Altera README
    Descrição e estrutura do projeto atualizadas no README.md para fornecer informações detalhadas sobre o Robô Entregador, seu desenvolvimento e recursos.
2026-09-28 Sobe o manual de utilização da simulação no TinkerCad
    Corrije os erros do arquivo anterior melhorando o manual
